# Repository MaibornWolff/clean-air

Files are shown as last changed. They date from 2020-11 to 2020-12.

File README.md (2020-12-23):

# Clean Air Device - an open UV-C aircleaner unit

## What is this?

This repository contains the building plans to build a DIY-air-cleaner based on UV-C radiation - the "cleanair" device.
The large device consists of 6 36W UV-C lamps in a flight case with extra space for electronics and the ESP32 control unit. The small one is able to handle up to 4 55W UV-C lamps and can be printed using a 3D printer capable of printing at least 22cm x 22cm blocks.

### Anycase Version

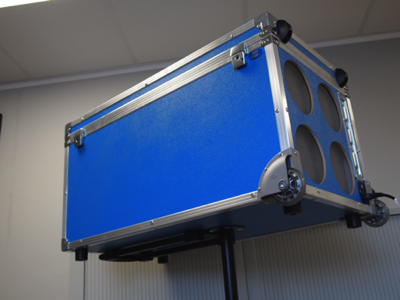
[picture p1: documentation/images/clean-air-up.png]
Clean Air Device
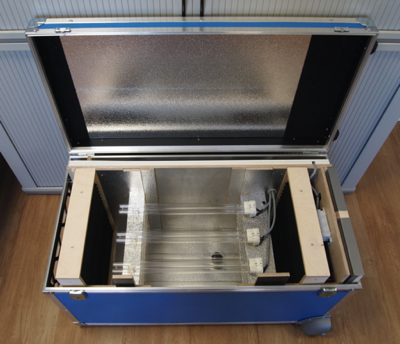
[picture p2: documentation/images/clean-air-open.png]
Clean Air Device
 

### 3D printable Version

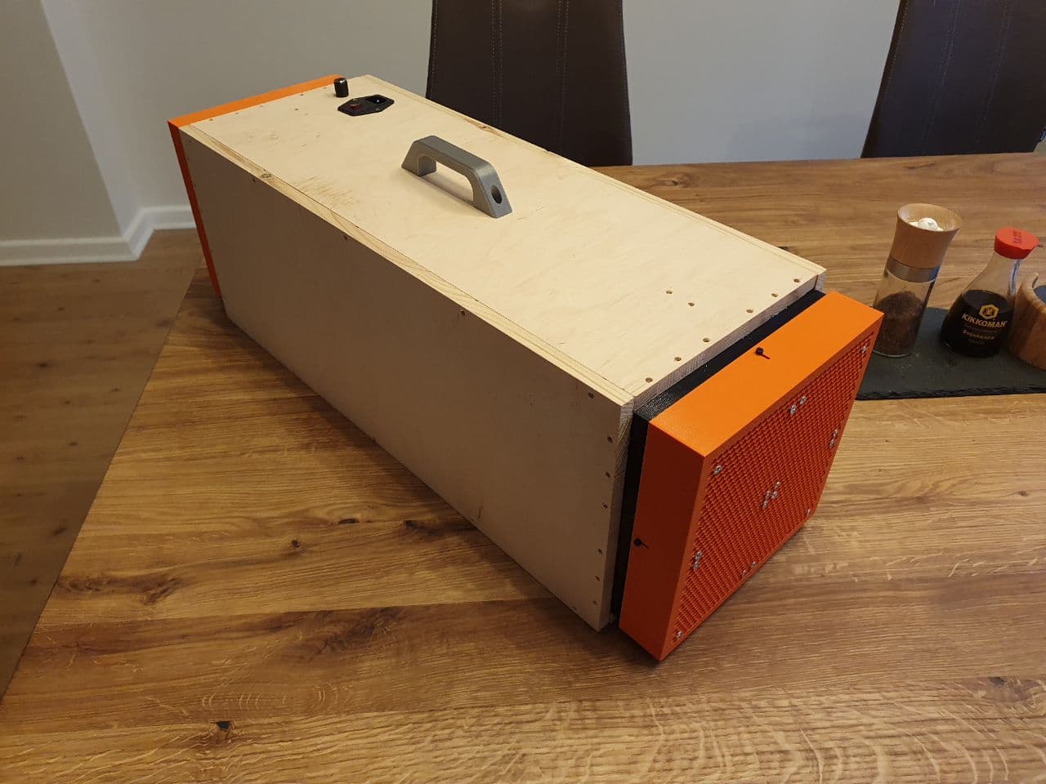
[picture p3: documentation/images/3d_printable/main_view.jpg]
3D printable Clean Air Device

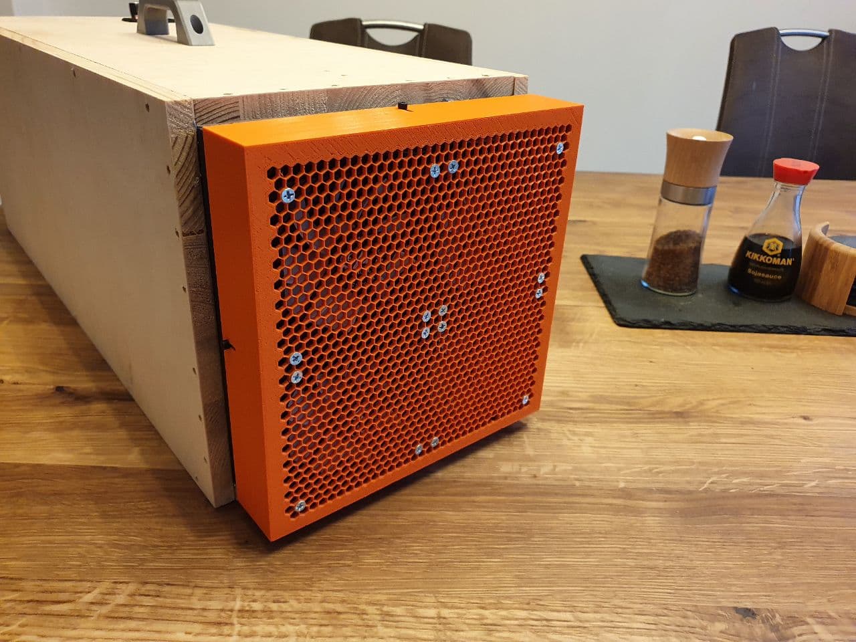
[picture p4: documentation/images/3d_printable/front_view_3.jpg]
3D printable Clean Air Device

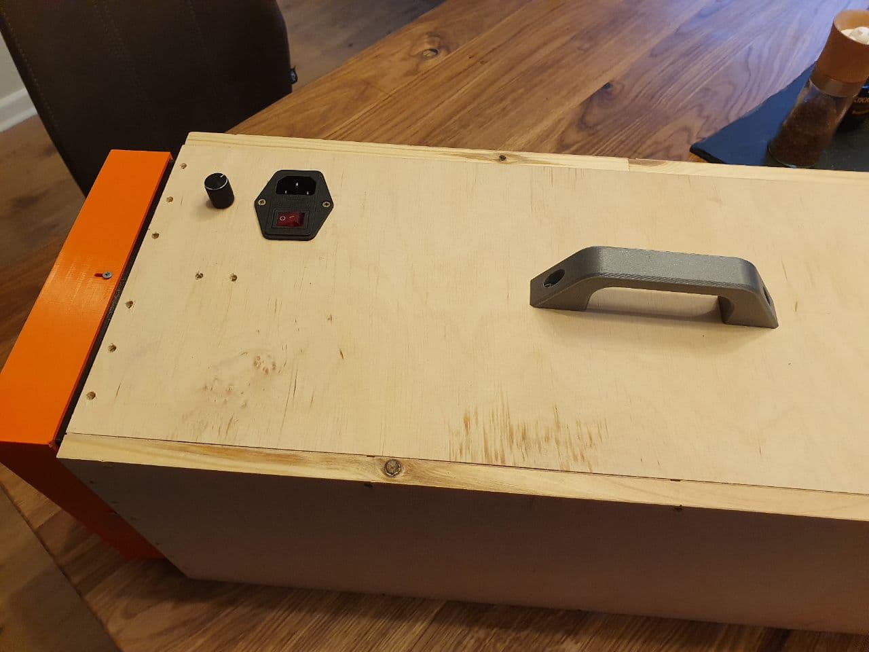
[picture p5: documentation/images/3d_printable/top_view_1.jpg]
3D printable Clean Air Device


## Why would I need this (what is the purpose)?

It seems reliable, that ultraviolet light (especially the UV-C variant) can help kill viruses.
On the other hand, UVC is dangerous to eyes and skin.

At MaibornWolff we put our engineering minds to it and created a solution which works for us.

**We build a mobile, safe container with UVC lights inside.**

Here are some reading information sources, if you want to read up on various opinions:

- https://www.medrxiv.org/content/10.1101/2020.05.31.20118588v3
- https://www.bbc.com/future/article/20200327-can-you-kill-coronavirus-with-uv-light
- https://www.cuimc.columbia.edu/news/far-uvc-light-safely-kills-airborne-coronaviruses
- https://pubmed.ncbi.nlm.nih.gov/32547908/

We estimated the irradiance inside the device as described in the [calculation (PDF)](documentation/theory.pdf).

## Getting started

In order to get started you have to decide if you want to build the large device or the small one. The large is device is mostly build by hand where the smaller one can be 3D-printed.

More information can be found in the [documentation section](documentation/README.md).

## Warning!

This device uses UV-C lamps which will damage skin and eyes. BE CAREFUL AND DO NOT TURN THE LAMPS ON OUTSIDE THE CASING!
Furthermore be aware of working with High Voltage for the lamps. CAUTION HIGH VOLTAGE!

## FAQ

### Why is it free?

We at MaibornWolff believe we have a responsibility to society, especially in these difficult times. As an IT company we had a good business year, regardless of Corona, and now it is time to use our knowledge in creating IT solutions to build an affordable and free air cleaner everyone can use.
We will not build our own "MaibornWolff Air Cleaner" unit and sell it. We have no whatsoever financial interest. Instead, we encourage you to help us make the device better, more easy to use, more cheap to produce, so everyone - companies, schools, kindergardens - could probably have one.

### What license are you using?

The code and documentation is licensed under the [MIT](LICENSE) license. The hardware documentation, build plans and 3d files are licensed under the [Creative Commons Attribution 3.0 Unported](cc-by-sa-3.0-unported.txt) license.

### How can I help?

Have a look at the [CONTRIBUTING](CONTRIBUTING.md) documentation. You can also join our [Slack Channel](https://maibornwolffcleanair.slack.com/) to get in touch with us.

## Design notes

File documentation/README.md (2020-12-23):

# Documentation

The documentation covers all information around the UV-C clean air units.

## DIY Hardware

### Calculations

Estimations about the irradiance and considerations about the room size for which such a device could be feasible are located [here](theory.pdf).

### 3D printable device

The small 3D printable model is a UV-C cleaner with up to 4 lamps and up to 8 fans. Based on our calculations the small device is capable of handling rooms with a size of up to 25,3m² (assuming 2.5m ceiling height), using 4x 55W UV-C lamps and fans with a total throughput of 380m³/h.

See [3D model documentation](3dmodel.md).

### Wooden device

The wooden device is a full sized DIY case, specced with 6 UV-C lamps and 4 fans.

See [wooden model documentation](allWoodModel.md).

### Electronics

- GPIO Pin 33 is to control the main fans via PWM signal.
- GPIO Pin 26 is to control the auxiliary fan via PWM signal.
- GPIO Pin 23 is to read the temperature coming from the temp sensor.
- GPIO Pin 21 connects to the "clock" of the rotary encoder (if in wrong dir, needs to get swapped with wire from Pin 17)
- GPIO Pin 17 connects to the "DT" of the rotary encoder (if in wrong dir, needs to get swapped with wire from Pin 21)
- GPIO Pin 16 connects to the "SW" of the rotary encoder.

Wire up the low voltage part like that:

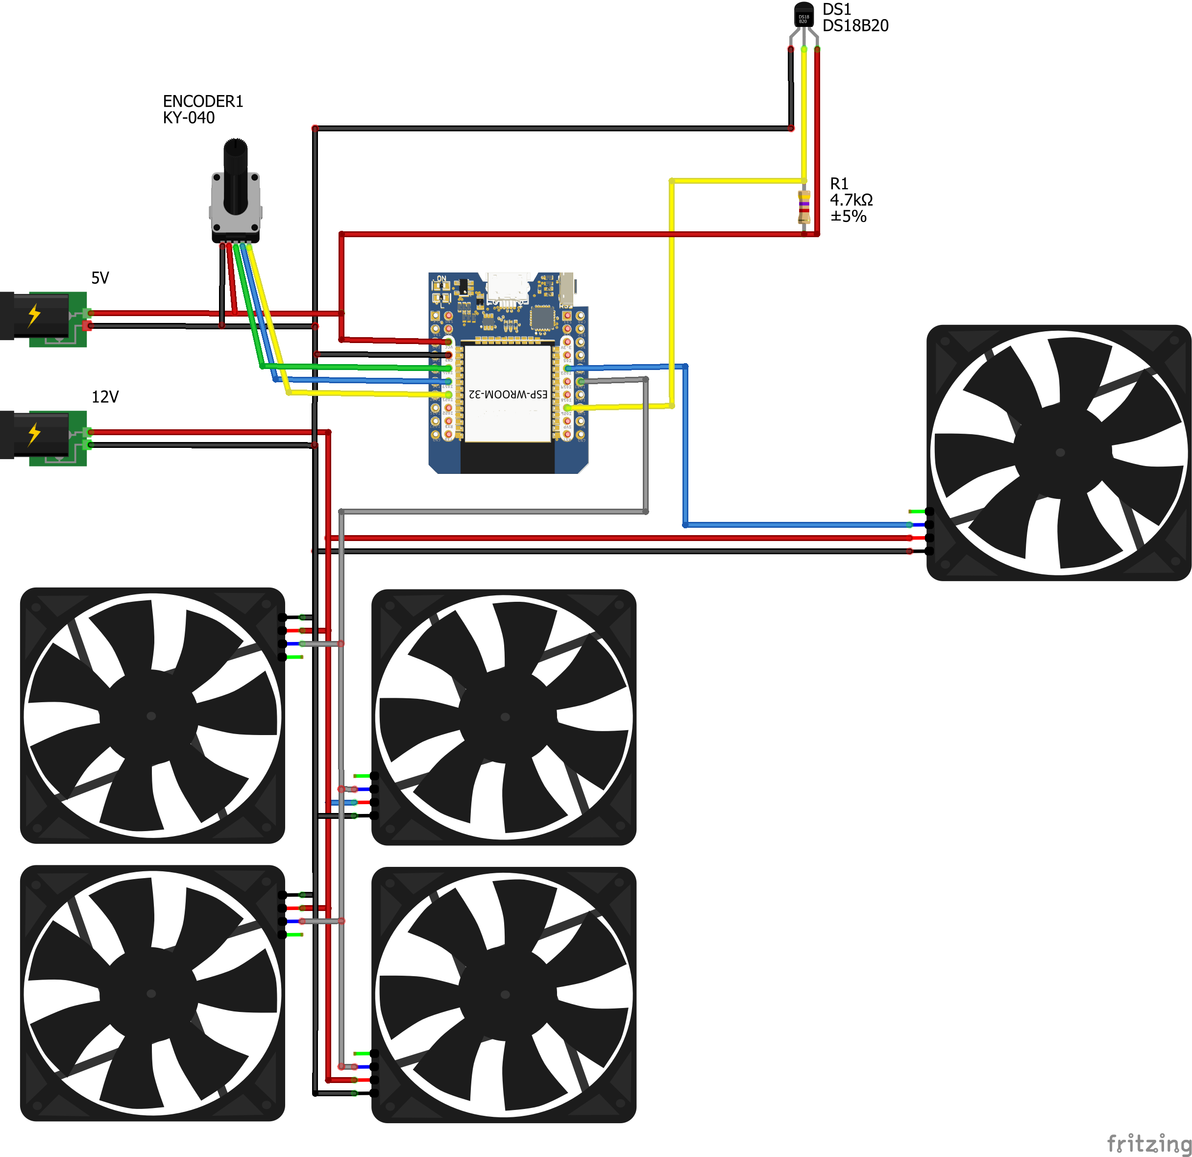
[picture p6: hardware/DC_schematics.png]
Low voltage schematics


The high voltage part is more dependent on the inverter as well as the plugs you use. On top of that it is more dangerous to work with 230V. If you do not know what you are doing you might rather want to look for professional help! Due to that a schematic for the high voltage part will not be provided. The individual recommended parts can be found within the specific devices documentation.

## Software

Use a tool like e.g. [ESPHome-Flasher](https://github.com/esphome/esphome-flasher) to flash the latest release onto your Wemos. If you'd like to build the software yourself, go to the Building section.

### Building

See [building documentation](software.md).

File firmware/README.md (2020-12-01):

## Instructions for Linux

- Install platformio.

- Install (udev rules)[https://docs.platformio.org/en/latest/faq.html#platformio-udev-rules].

- Add yourself to the dialout and tty group:

```sh
sudo usermod -a -G tty $USER
sudo usermod -a -G dialout $USER
sudo usermod -a -G plugdev $USER
```

Disconnect your board, then log out and log in again for the changes to take place. 

Check if your ESP32 is connected:

```sh
ll /dev | grep ttyUSB*
```

You should then be able to flash the code onto your board by running

```sh
platformio run --target upload --target monitor
```

Afterwards, an access point should spawn (namend ```CleanAirDevice```). The password is ```12345678```. Afterwards, the configuration page should be reachable under e.g. ```http://172.217.28.1/_ac``` (you need to fill in the correct IP address, of course).

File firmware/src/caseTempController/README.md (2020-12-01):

# Case Temperature Controller

Sub-program for regulating a PWM controlled fan to keep a steady temperature within the case.

Written for ESP32, Xinda Temperature Sensor, Noctua NF-A4x20 in C.

This program is basically implementing a PID controller. To understand the underlying calculation, check the following wikipedia article: https://en.wikipedia.org/wiki/PID_controller#Alternative_nomenclature_and_forms

# Circuit Diagram

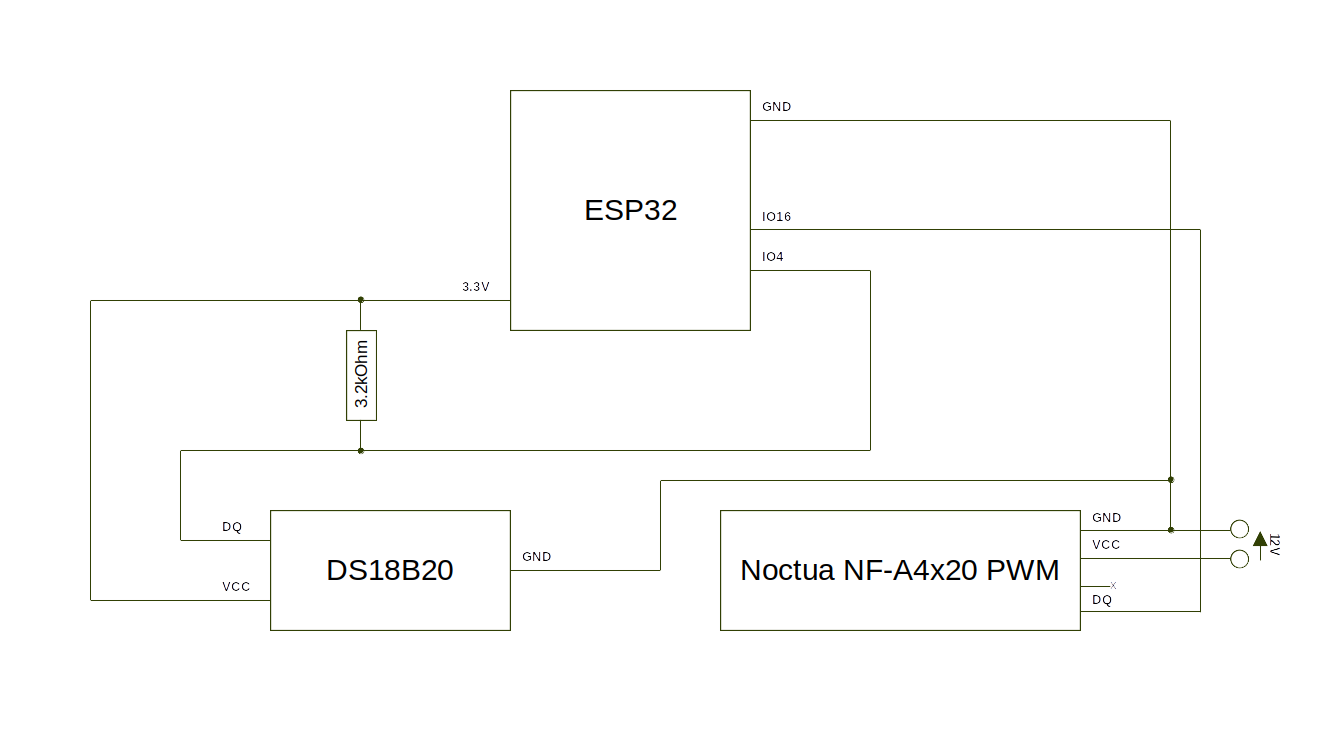
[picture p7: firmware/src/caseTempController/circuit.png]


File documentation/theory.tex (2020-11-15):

% !TEX encoding = UTF-8 Unicode
\documentclass[12pt]{scrartcl}
\usepackage{amsmath}
\usepackage{graphicx}
\usepackage{hyperref}
\usepackage{url}
\usepackage[utf8]{inputenc}
\usepackage{units}

\author{Michael Kiefer}\publishers{MaibornWolff GmbH, Versmannstr. 2, 20457 Hamburg}
\title{Calculations for the Clean-Air UVC device}

\begin{document}
\maketitle{}

\section{Concept}
We consider a set-up with air flowing through a cylinder, assuming the flow is independent of the position in the cylinder. At the center of the cylinder, we have the UVC lamp (a fluorescent tube). 
We want to calculate the energy that gets deposited on a virus particle while passing through the cylinder. The worst case is a virus passing at the wall of the cylinder, with the greatest distance to the lamp.

At that position, we have an Irradiance $I$ as
\begin{equation}
I   = \frac{E}{A_{\text{surface}}},  \label{eqn:irradiance}
\end{equation}
with the Energy $E$ and the side surface of the cylinder $A_{\text{surface}}$,

The outer surface of the tube is determined by the length $l$ and the radius $r$ of the tube as

\begin{equation}
A_{\text{surface}} = 2\pi r l.  \label{eqn:surface}
\end{equation}

The energy is determined by the power $P$ emitted by the lamps within the time $t$ that it takes for a volume element to pass through the irradiated part of the tube

\begin{equation}
E = P  t  \label{eqn:energy}
\end{equation}

We derive the time from the air flow $\Phi$, the volume $V$ that passes through the tube in a given time.
\begin{align}
\Phi &= V / t\\
\Rightarrow t &=V / \Phi
\end{align}

The volume is given by the geometry of the cylinder, using length and base area $A_{\text{base}}$
\footnote{we do not use the cylinder's radius fo calculating the area here, as we want to keep it for the generalization in section \ref{sect:multitube}.}
\begin{equation}
V = l A_{\text{base}} \label{eqn:volume}
\end{equation}

With equations \eqref{eqn:energy}, \eqref{eqn:volume} and \eqref{eqn:surface} in \eqref{eqn:irradiance}, we obtain
\begin{equation}
I =\frac{P }{\Phi } \frac{A_{\text{base}}}{2 \pi r }\label{eqn:irradiance_final}
\end{equation}

\section{Multiple lamps}\label{sect:multitube}
We want to estimate the irradiance created by multiple lamps at a certain position in our setup. At such a position, we can calculate the irradiance $I_i $ caused by each of the lamps $i$ with \eqref{eqn:irradiance_final} using the distance to the lamp as $r_{i}$. The resulting irradiance is simply the sum of these\footnote{$P$ in this case is the sum of the powers of the individual lamps $P_i$.}.
\begin{equation}
I_{\text{total}}=  \sum_{i} I_i = \frac{P A_{\text{base}}}{\Phi 2 \pi}  \sum_{i} \frac{1}{ r_i }
\end{equation}

In order to disable the virus particles, we need to expose them to a certain level of irradiation. With this targeted value $I_{\text{target}}$ given, we can calculate the maximum flow $\Phi_{\text{max}}$ that our device can process as

\begin{equation}
\Phi_{\text{max}}=  \frac{P A_{\text{base}}}{I_{\text{target}} 2 \pi}  \sum_{i} \frac{1}{ r_i }
\end{equation}

\section{Application to the MaibornWolff clean air device}

\begin{figure}
   \centering
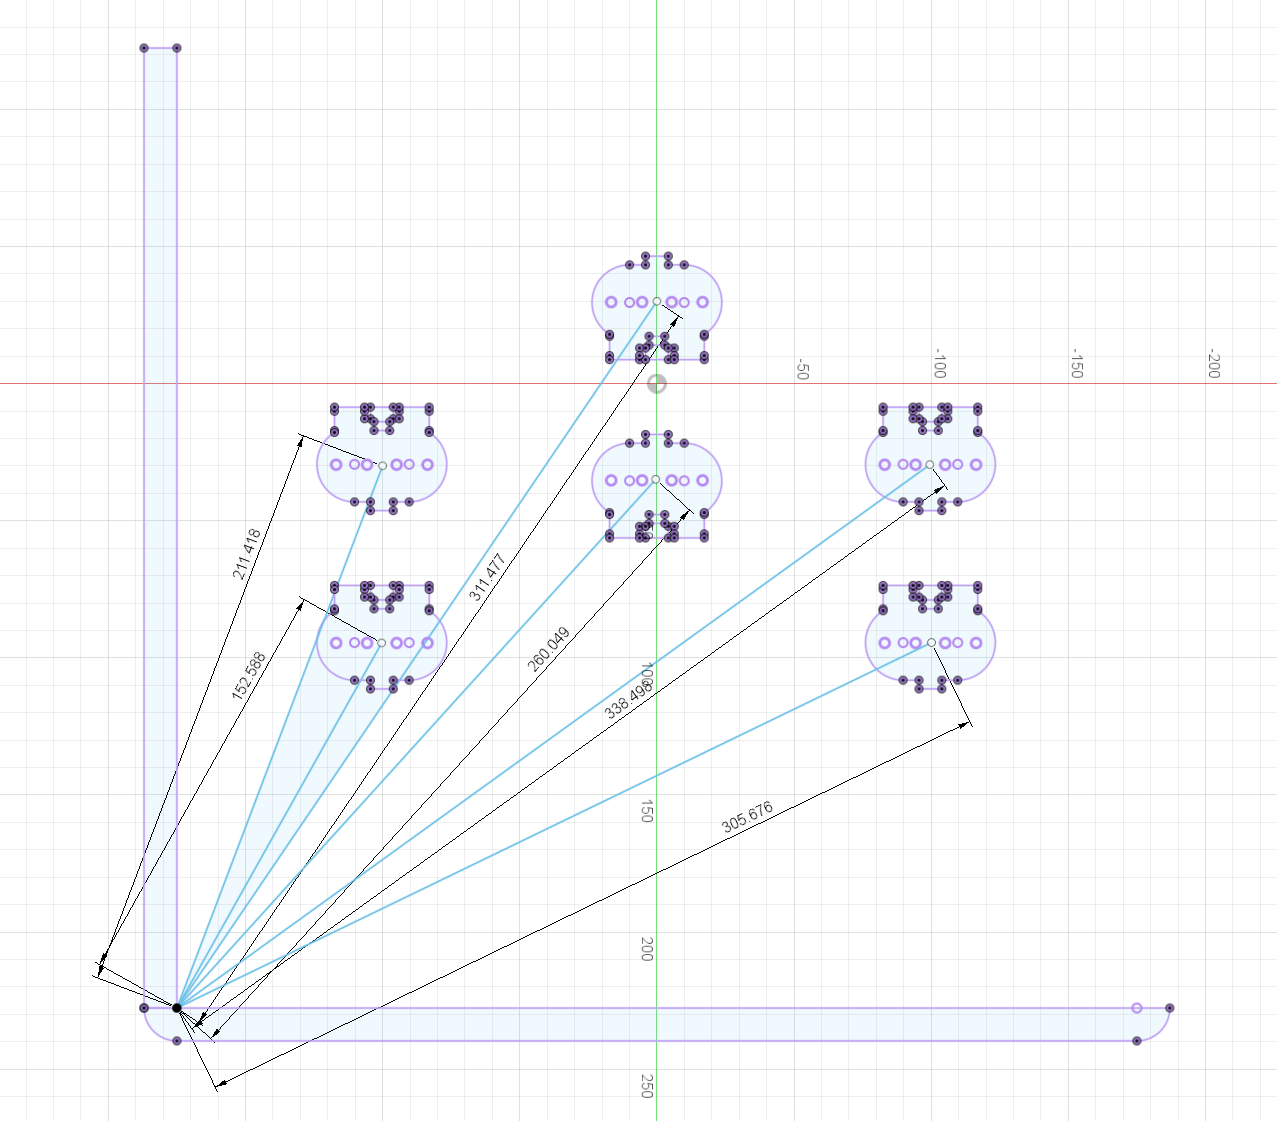
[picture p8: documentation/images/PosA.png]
    % requires the graphicx package
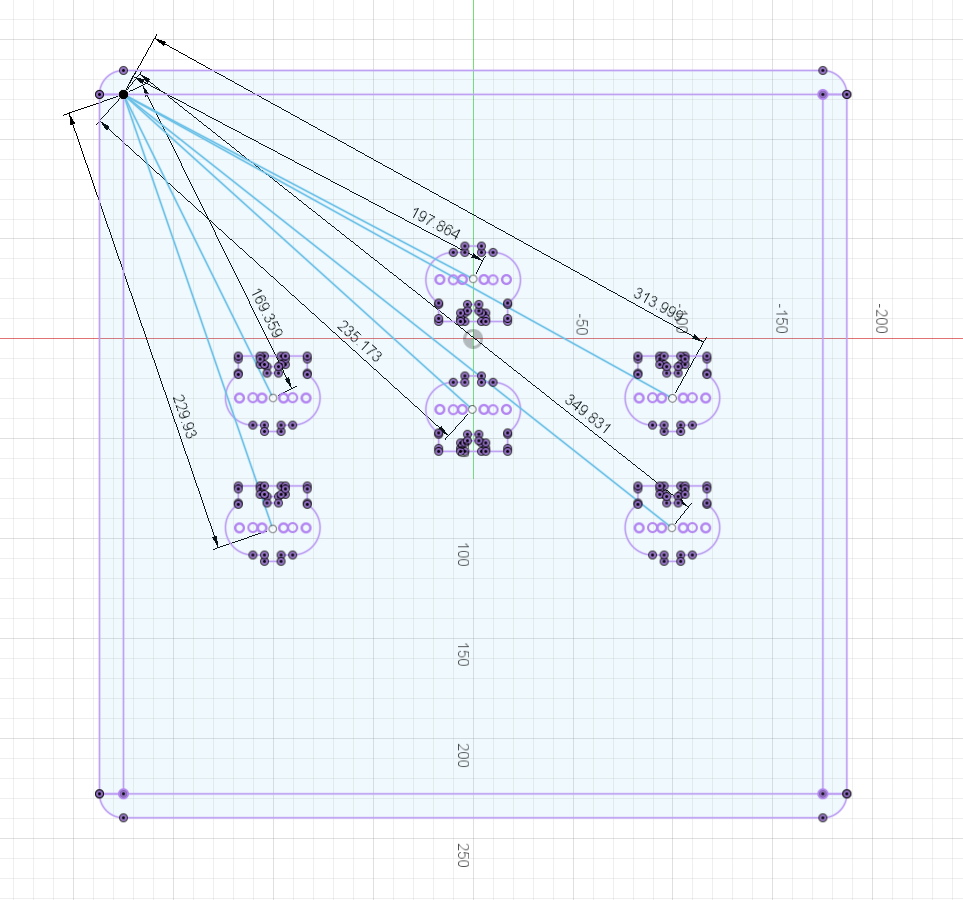
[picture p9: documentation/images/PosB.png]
    % requires the graphicx package
   \caption{Distances at position A (left) and B (right)}
   \label{fig:distances}
\end{figure}

Numbers on the irradiation dose vary. 
In order to deactivate coronavirus particles, \cite {ozog}  says that an irradiation of $\unit[10]{J/m^2}$ is sufficient. However, \cite{bianco} says that an irradiation of $\unit[37]{J/m^2}$ is needed. In \cite{hessling} this value is given as the probable value for the log-reduction dose which would mean that such an irradiation would at least deactivate 90\% of the virus particles. For the ongoing calculation, we aim at an irradiation with $\unit[120]{J/m^2}$ which would mean a log-3 reduction in case of the number given by \cite{hessling}.

In our set-up, the lamps each consume $\unit[36]{W}$ in electrical power and emit $\unit[12]{W}$ of UVC light.

The two sets of distances given in figure \ref{fig:distances} describe the positions that are furthest away from the lamps and thus the places where the irradiation is the weakest.

Using the excel sheet attached in the source repository, we calculate that the maximum throughput the device can tend to is in the range of $\unit[1000]{m^3/h}$. The WHO recommends an exchange rate of 6 air changes per hour \cite{who}. Assuming a height of $\unit[2.5]{m}$, this means that one device is appropriate for a room of up to $\unit[66]{m^2}$.

\begin{thebibliography}{9}

\bibitem{hessling}
   Heßling, Martin et al. 
   “Ultraviolet irradiation doses for coronavirus inactivation - review and analysis of coronavirus photoinactivation studies.”
   GMS hygiene and infection control vol. 15 Doc08. 
   14 May. 2020, 
   doi: https://doi.org/10.3205/dgkh000343
   
\bibitem{bianco}
  Andrea Bianco et al.,
  "UV-C irradiation is highly effective in inactivating and inhibiting SARS-CoV-2 replication"
  medRxiv 2020.06.05.20123463
  doi: https://doi.org/10.1101/2020.06.05.20123463 
  
\bibitem{ozog}
  David M. Ozog, et al.,
  The Effect of Ultraviolet C Radiation Against SARS-CoV-2 Inoculated N95 Respirators
  medRxiv 2020.05.31.20118588; doi: \url{https://doi.org/10.1101/2020.05.31.20118588}

\bibitem{who}
  Coronavirus disease (COVID-19): Ventilation and air conditioning in health facilities
  29 July 2020  Q\&A
  \url{https://www.who.int/news-room/q-a-detail/coronavirus-disease-covid-19-ventilation-and-air-conditioning-in-health-facilities}

\end{thebibliography}

\end{document}

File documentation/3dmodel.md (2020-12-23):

## Documentation

The printing time for the 3D Printable Model is about 85 hours (with 0.4mm nozzle, 0.2mm layer height)
cumulated, and you'll need about 1,5kg of PETG or ASA. You should not use PLA since it is not UV resistant. In
total, the 3D-printable device will cost you about 175€ excl. the print material, the electrical bill and your time.
The UV-C aircleaner can also be found on [thingiverse](https://www.thingiverse.com/thing:4649824)

### Used Hardware

For the .stl files please check the folders within this directory. The also contain a file "required_parts.txt" which
describes the amount required of each part. All other non-3D-printable parts are listed within this document.

#### List of common parts with links:

| # | Description | Note | Link | Price in €  |
| --- | --- | --- | --- | --- |
| 1/2 | Inverter 55W | can be adjusted according to wattage of lamps | [amazon.de](https://www.amazon.de/gp/product/B00I0QUFR4/) | 13,54 |
| 1 | 12V PSU | | [amazon.de](https://www.amazon.de/gp/product/B00A9UP8P8/) | 17,99 |
| 1/2 | UVC Mount | | [amazon.de](https://www.amazon.de/gp/product/B0018LGB4E/) | 4,96 |
| 2/4 | UVC Lamp 55W | can be adjusted to up to 95W | [amazon.de](https://www.amazon.de/gp/product/B002VLGJOW/) | 19,13 |
| 1 | 5V PSU | Optional, a 12v to 5v converter can also be used | [amazon.de](https://www.amazon.de/gp/product/B079138QY1/) | 8,46 |
| 1 | AC Plug with fuse | | [amazon.de](https://www.amazon.de/gp/product/B01FQVM9EM/) | 6,99 |
| 4/8 | 12V 92mm PWM Fan | either use only 4 in the front or 4 in the front and 4 in the back | [amazon.de](https://www.amazon.de/ARCTIC-F9-PWM-Standardgeh%C3%A4use-L%C3%BCfterdrehzahl/dp/B00H3SVWF4/) / [mindfactory.de](https://www.mindfactory.de/product_info.php/Titan-TFD-9225H12ZP-KE-RB--92x92x25mm-2700-U-min-10-25-dB-A--schwarz-we_1030365.html) | 3,60 / 9.02 |
| 1 | ESP32 Mini | | [amazon.de](https://www.amazon.de/AZDelivery-Bluetooth-Internet-Entwicklungsboard-kompatibel/dp/B08BTRQNB3/) | 8,99 |
| 1 | Rotary Knob KY-040 | | [amazon.de](https://www.amazon.de/WayinTop-Encoder-Drehgeber-Drehwinkelgeber-Druckknopf/dp/B07T3672VK/) | 9,99 |
| - | M3 Screws 15mm | use a lot | - | - |
| - | M3 Screws 30mm | use a few | - | - |
| - | Wood Screws 15mm | use a lot | - | - |
| 1 | Aluminum self adhesive tape | A roll is enough to build one hybrid wooden device | [amazon.de](https://www.amazon.de/gp/product/B08C5JPV12) | 10,00 |
| - | Cables | use a lot and in different variations, ref to the specs of the inverter | - | - |

#### 3D Printable Aluminum Hybrid Model:

| # | Description | Link | Price in € |
| --- | --- | --- | --- |
| 4 | Aluminum L Profile | [ebay.de](https://www.ebay.de/itm/Aluminium-Winkel-Alu-L-Profil-Alu-Schiene-Aluprofil-Winkelprofil-Aluwinkel/282319979439)  | 2,42 |
| 4 | Aluminum Plate 600x200mm | [ebay.de](https://www.ebay.de/itm/0-5-4mm-Aluminium-Blech-Platte-Alublech-Aluplatte-Feinblech-mit-Schutzfolie/264476529936) | 18,45 |

#### 3D Printable Wood Hybrid Model:

| # | Description | Link | Price in € |
| --- | --- | ---- | --- |
| 2 | Wooden Plate 600x230mmx10mm | - | 5,00 |
| 2 | Wooden Plate 600x210mmx10mm | - | 5,00 |

#### Parts used from to other sources which need to be printed:

| # | Description | Link |
| --- | --- | --- |
| 1 | Knob | [thingiverse.com](https://www.thingiverse.com/thing:1465938) |
| 1 | Handle | [thingiverse.com](https://www.thingiverse.com/thing:4619895) |

#### What you'll need in addition to that

- An (electric) screwdriver
- Wood/Metal drills (and electric screwdriver/o.e.)

### How to build it

### Electronic Setup

Wire up the low voltage part like that:

Low voltage schematics

### ESP Control Unit

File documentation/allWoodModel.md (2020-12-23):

# DIY Version with items from your local hardware store

<p align="center">
  
</p>
This hardware version is mainly build out of wood, which can be cut to length by most hardware stores or in a home workshop. For the light shutters, a combination of angle-profiles and wooden mounts is used.
Those mounts can either be cut with a CNC, 3d printed or carved with hand tools. A technical drawing is included in this repository. Due to the different methods to produce this parts, those shutters need to either be glued, screwed or held otherwise in to place after installing them like shown in the animation above.

## Required Materials

### Wooden parts:

| # required | length | width | thickness | Note |
| --- | --- | ----- | --- | --- |
| 2 | 818mm  | 450mm | 9mm | sides |
| 2 | 450mm  | 350mm | 9mm | front and back |
| 3 | 800mm  | 350mm | 9mm | top, bottom and divider  |
| 8 | 350mm  | 10mm  | 10mm | wooden strip 10mm\*10mm  |
| 4 | 350mm  | 40mm  | 9mm | mounting for light tubes |
| 4 | 350mm  | 50mm  | 9mm | light filter mount |

### Electronics:

| # required | Description | Model suggestion | Link |
| --- | --- | --- | --- |
| 4 | 140mm PWM fan | Noctua NF-A14 | [amazon.de](https://www.amazon.de/-/en/Noctua-NF-A14-PWM-case-fan/dp/B00CP6QLY6) |
| 1 | 12V DC Supply | | [amazon.de](https://www.amazon.de/-/en/Innovate-Transformer-12-24-Driver-Supply/dp/B01AALEXS8) |
| 6 | UV-C 36W disinfection lamp | Philips TUV PL-L 36W | [amazon.de](https://www.amazon.de/-/en/Philips-PLL36-865-2G11-6500K/dp/B0019CG6D8) |
| 3 | Electric ballast | Philips EVG HF-S 2x 36 W  | [amazon.de](https://www.amazon.de/-/en/Philips-Electronic-Ballast-Fluorescent-Compact/dp/B00OTXR71E/) |
| 6 | lamp holder | 2g11 | [amazon.de](https://www.amazon.de/-/en/Vossloh-Assembly-Frame-Mount-2G11-PL/dp/B0018LGB4E) |
| 6 | lamp clips | | [amazon.de](https://www.amazon.de/-/en/Houben-101393-mechanical-accessory-4014364013947/dp/B000ONOQF8) |
| 1 | 50mm PWM fan | | [amazon.de](https://www.amazon.de/-/en/Noctua-NF-A4x10-PWM-Premium-Quiet/dp/B07DXRNYNX) |
| 1 | temperature sensor | ds18b20 | [amazon.de](https://www.amazon.de/-/en/AZDelivery-DS18b20-1m-DS18B20-Parent/dp/B01MZG48OE/) |
| 1 | ESP32 | Wemos D1 ESP32 | [amazon.de](https://www.amazon.de/-/en/AZDelivery-Bluetooth-Internet-Development-Compatible/dp/B08BTLYSTM/) |
| 1 | rotary encoder | | [amazon.de](https://www.amazon.de/-/en/WayinTop-KY-040-Encoder-Rotating-Arduino/dp/B07T3672VK/) |
| 1 | 12V/5V DC/DC | | [amazon.de](https://www.amazon.de/-/en/AZDelivery-XL4015-Voltage-Converter-1-25-32/dp/B07SRXR1VT) |
| 1 | 4.7k Ohm Resistor | | [amazon.de](https://www.amazon.de/-/en/Metal-film-resistor-pack-10/dp/B01LXS3YX2/) |
| use a lot  | M3 Woodscrews 25mm | e.g. Spax | - |
| use a lot  | Wires, 1mm² should fit the inverter | | - |
| 1 | Aluminum self adhesive tape | A roll shouldbe be enough | [amazon.de](https://www.amazon.de/gp/product/B08C5JPV12) |

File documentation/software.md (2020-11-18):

# Software
The firmware of the ESP32 control unit is used to control the fan speed knob and to provide over-the-air features like automatic updates.

This documentation shows how to build the firmware on your local machine.

## Prerequisites

### PlatformIO
Platform IO is used to build the ESP firmware. PlatformIO is a cross-platform, cross-architecture, multiple framework, professional tool for embedded software development.
The documentation of platform io can be found here: https://docs.platformio.org/en/latest/

In order to build the software you need the PlatformIO CLI installed on your system. The main documentation can be found here: https://docs.platformio.org/en/latest/core/installation.html#piocore-install-shell-commands

Short documentation for Linux and MacOS:

Platformio is a python cli tool. You need python3 to run it and it can be installed using pip:

```
pip install platformio
```

For more complex installation variante (virtual python env or Windows) please refer to the  main documentation (see link above)

### Drivers - MacOS specific
#### ESP32
For the ESP32 uses the CH340 usb2serial chipset no further drivers are needed.

#### ESP8266
In order to acceess a D1 Mini/NodeMCU a USB to serial driver needs to be installed to use the CP210x USB to UART Bridge VCP. It can be found here:
https://www.silabs.com/Support%20Documents/Software/Mac_OSX_VCP_Driver.zip

Further documentation:
* https://cityos-air.readme.io/docs/1-mac-os-usb-drivers-for-nodemcu#13-nodemcu-v10-driver

#### Troubleshooting

After the installation of the drivers, it should be possible for you to connect the device via USB establish a serial connection. When entering

```
ls /dev/cu.*
```

you should see a device that is named something like:

```
/dev/cu.usbserial-0203810B
```

If this is not the case, try the following:

- [Check](https://www.dignited.com/50330/usb-data-cable-vs-usb-charging-cable/) if your USB cable is actually able to transfer data and it's not just a charger cable.
- Follow the instructions listed [here](https://docs.espressif.com/projects/esp-idf/en/latest/esp32/get-started/macos-setup.html) to make sure your system is configured properly.
- If nothing helps, manually install the correct ESP32 driver for your system from [here](https://www.ftdichip.com/Drivers/VCP.htm).

## Building

To build the firmware change in the CleanAir directory and issue the platformio run subcommand:

```
cd CleanAir
platformio run
```

To upload the firmware to your ESP32 issue the following command:

```
platformio run --target upload
```

Please note that you need to have configured the correct serial port to do the initial upload. To get a list of all available ports on your system you can run

```
platformio device list
```

If your upload port is not select automatically you can add the port configuration to your upload command:

```
platformio run --target upload --upload-port <upload port>
```

## Usage

## Further documentation

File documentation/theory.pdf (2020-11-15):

# Calculations for the Clean-Air UVC device

## Michael Kiefer

## November 12, 2020 MaibornWolff GmbH, Versmannstr. 2, 20457 Hamburg

## 1 Concept

We consider a set-up with air flowing through a cylinder, assuming the flow is independent of the position in the cylinder. At the center of the cylinder, we have the UVC lamp (a fluorescent tube). We want to calculate the energy that gets deposited on a virus particle while passing through the cylinder. The worst case is a virus passing at the wall of the cylinder, with the greatest distance to the lamp.
At that position, we have an Irradiance I as

I =

E

Asurface

, | (1)

with the Energy E and the side surface of the cylinder Asurface,
The outer surface of the tube is determined by the length l and the radius r of the tube as
Asurface = 2πrl. | (2)

The energy is determined by the power P emitted by the lamps within the time t that it takes for a volume element to pass through the irradiated part of the tube

E = P t | (3)

We derive the time from the air flow Φ, the volume V that passes through the tube in a given time.

Φ = V/t | (4)
⇒ t = V/Φ | (5)

1

The volume is given by the geometry of the cylinder, using length and base area Abase

1
V = lAbase | (6)

With equations (3), (6) and (2) in (1), we obtain

I =

P
Φ

Abase
2πr

(7)

## 2 Multiple lamps

We want to estimate the irradiance created by multiple lamps at a certain position in our setup. At such a position, we can calculate the irradiance Ii caused by each of the
lamps i with (7) using the distance to the lamp as ri | . The resulting irradiance is simply
the sum of these²

Itotal =

X

i

Ii =

P Abase
Φ2π

X

i

1
ri

(8)

In order to disable the virus particles, we need to expose them to a certain level of irradiation. With this targeted value Itarget given, we can calculate the maximum flow Φmax that our device can process as

Φmax =

P Abase

Itarget2π

X

i

1
ri

(9)

## 3 Application to the MaibornWolff clean air device

Numbers on the irradiation dose vary. In order to deactivate coronavirus particles, [3] says that an irradiation of 10 J/m²
is sufficient. However, [2] says that an irradiation of 37 J/m²
is needed. In [1] this value is given as the probable value for the log-reduction dose which would mean that such an irradiation would at least deactivate 90% of the virus particles. For the ongoing calculation, we aim at an irradiation with 120 J/m² which would mean a log-3 reduction in case of the number given by [1].
In our set-up, the lamps each consume 36W in electrical power and emit 12W of UVC light.
The two sets of distances given in figure 1 describe the positions that are furthest away from the lamps and thus the places where the irradiation is the weakest.
Using the excel sheet attached in the source repository, we calculate that the maximum throughput the device can tend to is in the range of 1000 m³/h. The WHO recommends an exchange rate of 6 air changes per hour [4]. Assuming a height of 2.5 m, this means that one device is appropriate for a room of up to 66 m²

1we do not use the cylinder’s radius fo calculating the area here, as we want to keep it for the generalization in section 2.
2P in this case is the sum of the powers of the individual lamps Pi

2

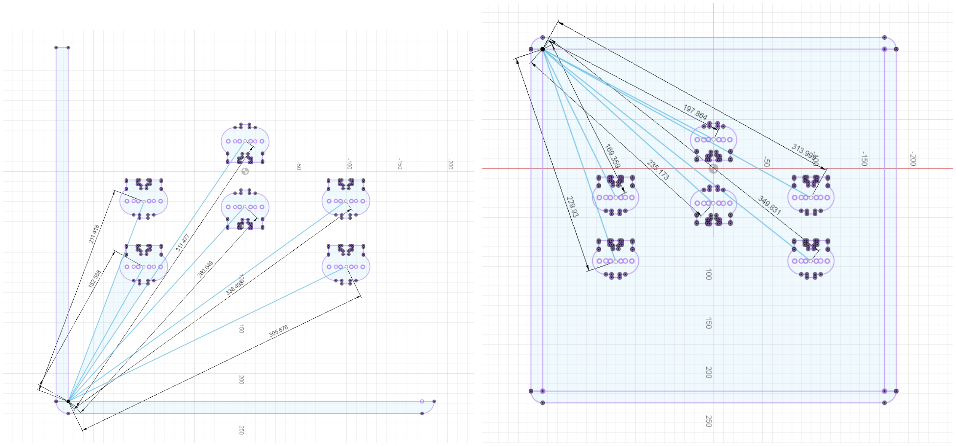
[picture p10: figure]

Figure 1: Distances at position A (left) and B (right)

## References

[1] Heßling, Martin et al. “Ultraviolet irradiation doses for coronavirus inactivation - review and analysis of coronavirus photoinactivation studies.” GMS hygiene and infection control vol. 15 Doc08. 14 May. 2020, doi: https://doi.org/10.3205/dgkh000343
[2] Andrea Bianco et al., ”UV-C irradiation is highly effective in inactivating and inhibiting SARS-CoV-2 replication” medRxiv 2020.06.05.20123463 doi: https://doi.org/10.1101/2020.06.05.20123463
[3] David M. Ozog, et al., The Effect of Ultraviolet C Radiation Against SARS-CoV-2 Inoculated N95 Respirators medRxiv 2020.05.31.20118588; doi: https://doi.org/10.1101/2020.05.31.20118588 (https://doi.org/10.1101/2020.05.31.20118588)
[4] Coronavirus disease (COVID-19): Ventilation and air conditioning in health
facilities 29 July 2020 Q&A https://www.who.int/news-room/q-a-detail/coronavirus-disease-covid-19-ventilation-and-air-conditioning-in-health-facilities (https://www.who.int/news-room/q-a-detail/coronavirus-disease-covid-19-ventilation-and-air-conditioning-in-health-facilities)

3

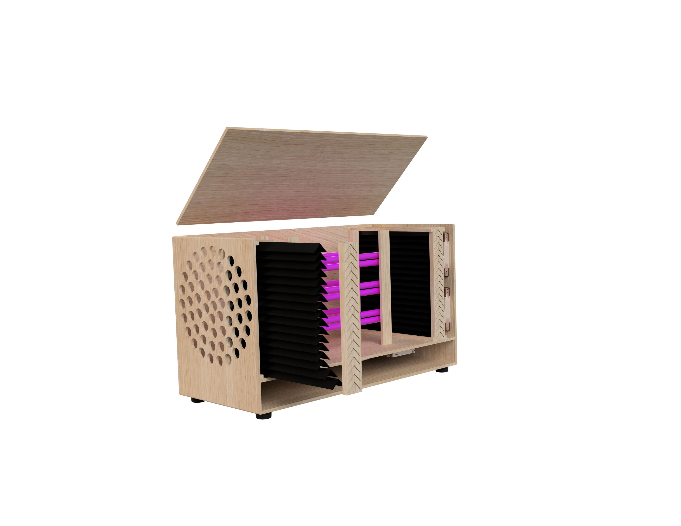
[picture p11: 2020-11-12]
hardware/all_wood/pictures/explosion2.png

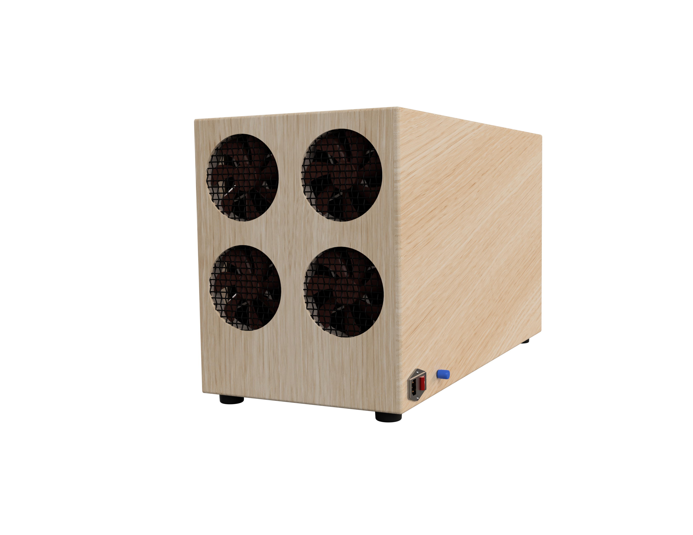
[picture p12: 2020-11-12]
hardware/all_wood/pictures/backview.png

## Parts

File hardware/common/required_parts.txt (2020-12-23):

2x honeycombfront (to your fan likes)
2x uv_back_holder
1x 230_protector
4x vorschaltgeräteschutz
1x wemos_case

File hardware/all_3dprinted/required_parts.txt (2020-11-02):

3D Prints:
- 2x lichtschutz
- 2x universalBoxPlate_uvc_holder
- 2x uvc_holder
- 16x universalBoxPlate_adapter
- 9x universalBoxPlate_clean
- 1x universalBoxPlate_io

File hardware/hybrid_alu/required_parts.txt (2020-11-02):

3D Prints:
- 2x lichtschutz
- 2x uvc_holder_alu
- 1x schablone_alu 

Other:
- 2x 60x20x0.3cm aluminum plates
- 4x Part #5

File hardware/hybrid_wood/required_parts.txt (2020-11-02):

3D Prints:
- 2x lichtschutz_wood
- 2x uvc_holder_wood
- 1x schablone_wood_narrow
- 1x schablone_wood_wide

Other:
- 2x 60x21x0.5cm wooden plates
- 2x 60x22x0.5cm wooden plates
- 4x Part #5

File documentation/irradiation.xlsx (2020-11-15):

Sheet: Position A
 |  | Position |  | UVC power |  | Box
Dimension | Lamp | distance from lamp |  | per lamp | total | length | width/height | base area | targeted irradiation | maximal flow
Symbol in PDF | i | ri | 1/ri | Pi | P | l |  | Abase | Itarget | Φmax
unit |  | mm | 1/m | W | W | mm | mm | m2 | J/m2 | m3/h
 | A | 211 | 4.739336493 | 12 | 72 | 400 | 350 | 0.1225 | 120 | 1036.686804 | 69.11245361
 | B | 152 | 6.578947368
 | C | 311 | 3.215434084
 | D | 260 | 3.846153846
 | E | 338 | 2.958579882
 | F | 305 | 3.278688525
 | Sum |  | 24.6171402

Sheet: Position B
 |  | Position |  | UVC power |  | Box
Dimension | Lamp | distance from lamp |  | per lamp | total | length | width/height | base area | targeted irradiation | maximal flow
Symbol in PDF | i | ri | 1/ri | Pi | P | l |  | Abase | Itarget | Φmax
unit |  | mm | 1/m | W | W | mm | mm | m2 | J/m2 | m3/h
 | A | 169 | 5.917159763 | 12 | 72 | 400 | 350 | 0.1225 | 120 | 1074.471415
 | B | 230 | 4.347826087
 | C | 198 | 5.050505051
 | D | 235 | 4.255319149
 | E | 324 | 3.086419753
 | F | 350 | 2.857142857
 | Sum |  | 25.51437266

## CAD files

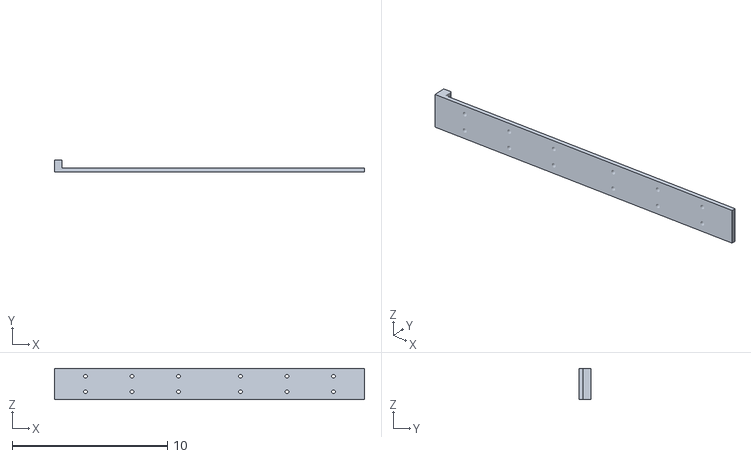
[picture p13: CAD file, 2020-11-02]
hardware/all_3dprinted/universalboxplate_adapter.stl
20.0 x 0.75 x 2.00

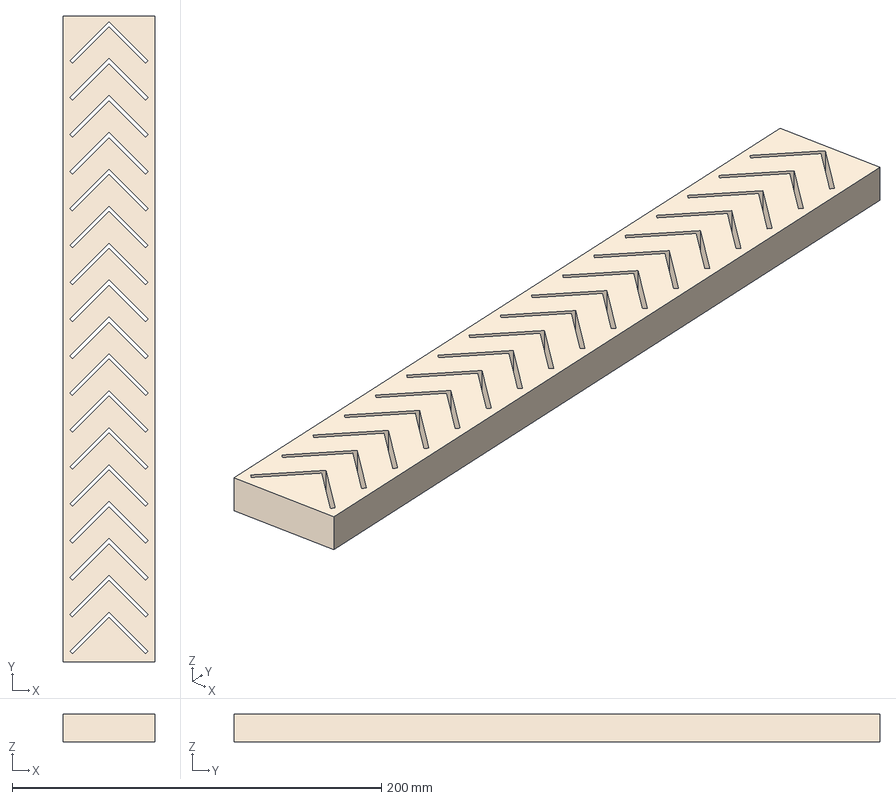
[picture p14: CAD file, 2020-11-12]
hardware/all_wood/light shutters/shutter_mount.step
50.0 x 350.0 x 15.0 mm

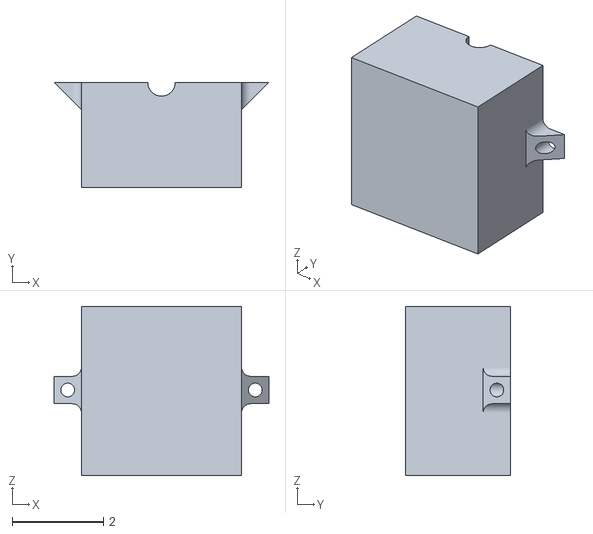
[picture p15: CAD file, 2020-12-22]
hardware/common/vorschaltgeräteschutz.stl
4.70 x 2.30 x 3.70

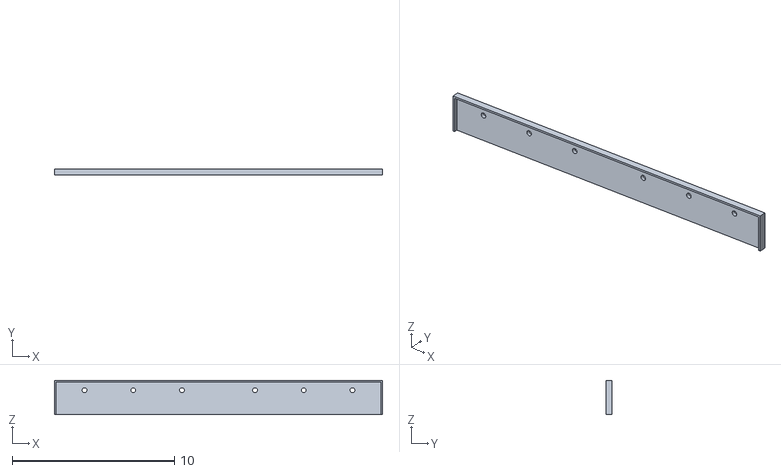
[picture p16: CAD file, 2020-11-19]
hardware/hybrid_alu/schablone_alu.stl
20.2 x 0.4 x 2.10

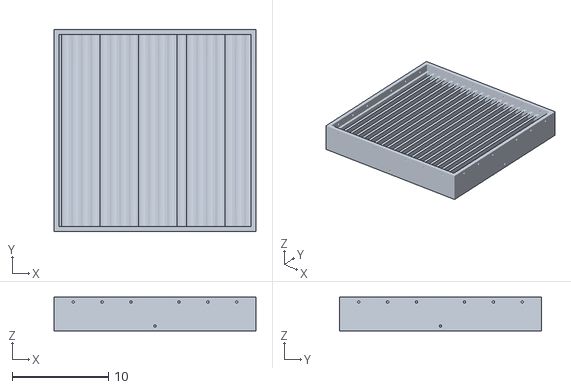
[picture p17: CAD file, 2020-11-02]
hardware/hybrid_wood/lichtschutz_wood.stl
21.0 x 21.0 x 3.50

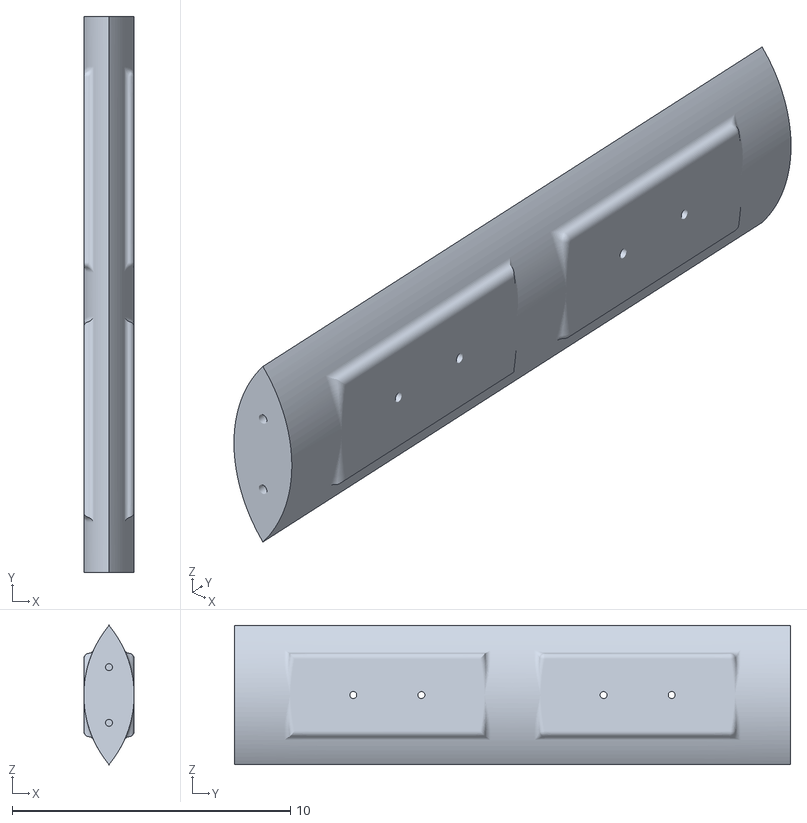
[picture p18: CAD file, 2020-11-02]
hardware/all_3dprinted/uvcholder.stl
1.81 x 20.0 x 5.00

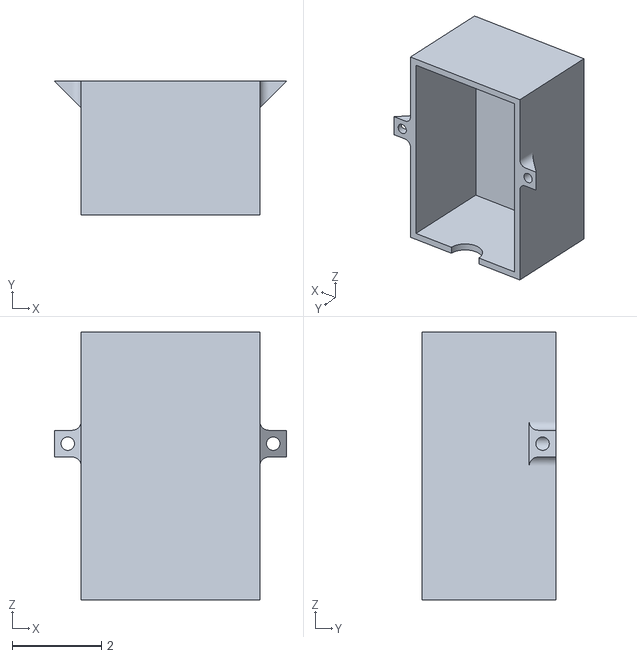
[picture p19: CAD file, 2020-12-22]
hardware/common/wemos_case.stl
5.20 x 3.00 x 6.00

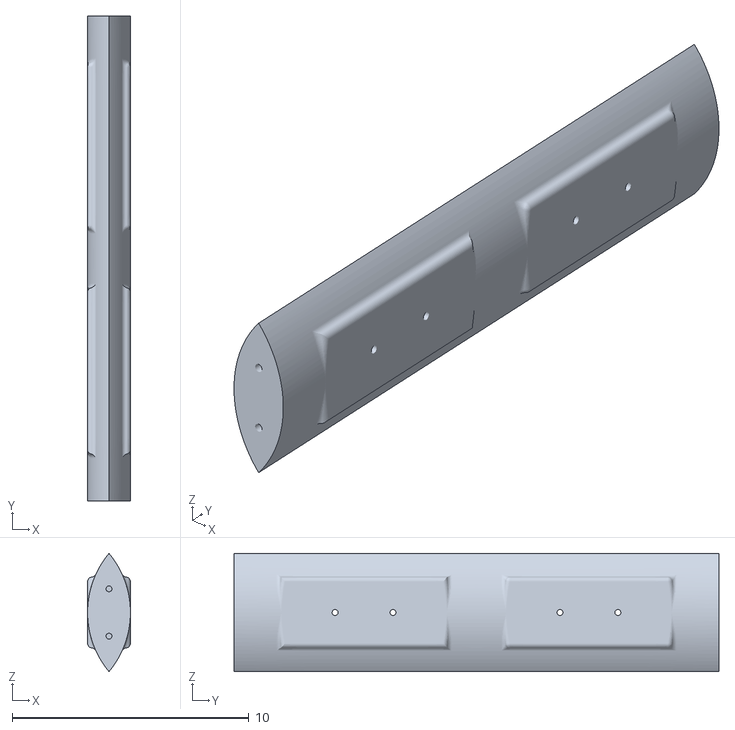
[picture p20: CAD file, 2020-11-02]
hardware/hybrid_alu/uvcholder_alu.stl
1.81 x 20.5 x 5.00

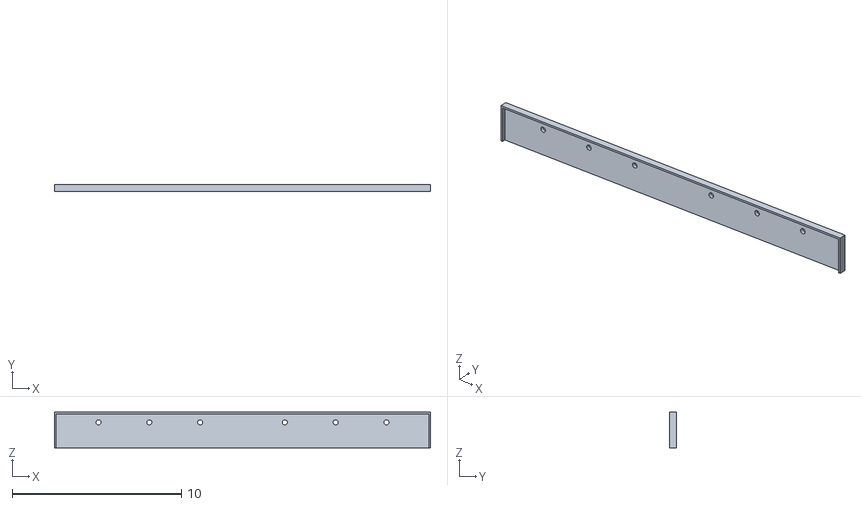
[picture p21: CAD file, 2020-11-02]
hardware/hybrid_wood/schablone_wood_wide.stl
22.2 x 0.4 x 2.10

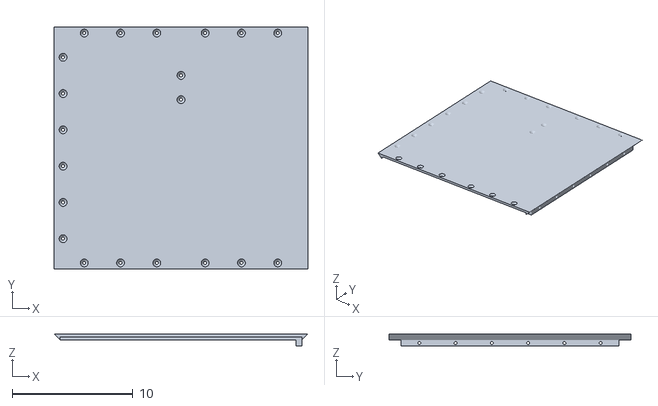
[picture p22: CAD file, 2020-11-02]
hardware/all_3dprinted/universalBoxPlate_uvc_holder.stl
21.0 x 20.0 x 1.00

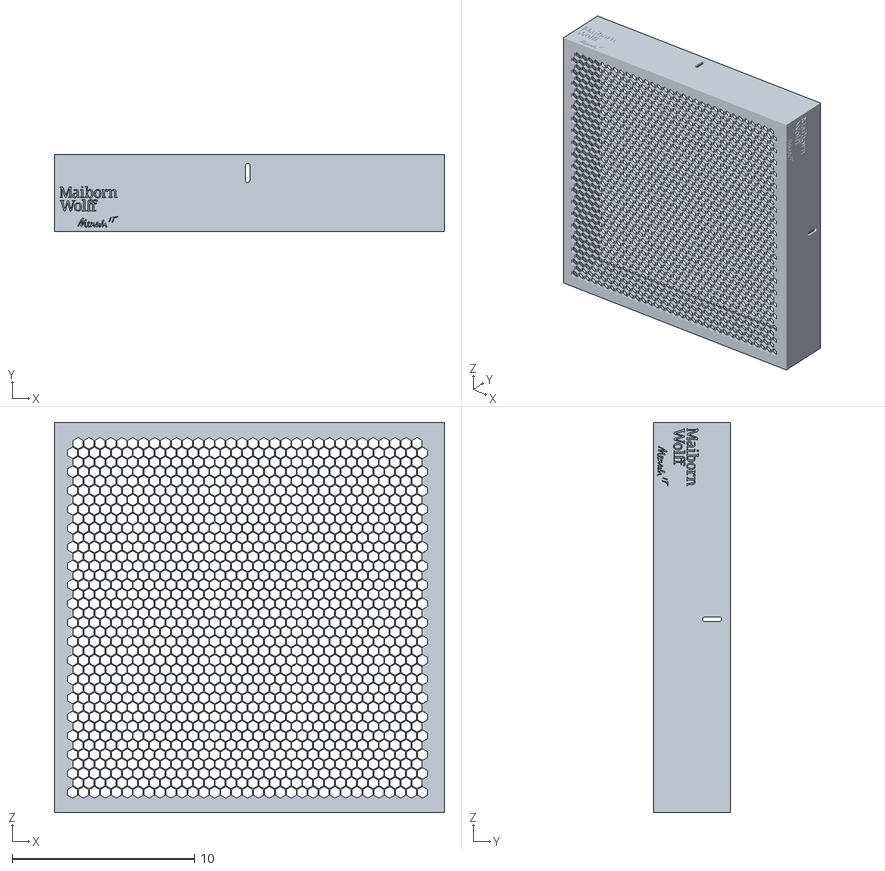
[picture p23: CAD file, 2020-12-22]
hardware/common/honeycombfront_normal_fan.stl
21.4 x 4.20 x 21.4

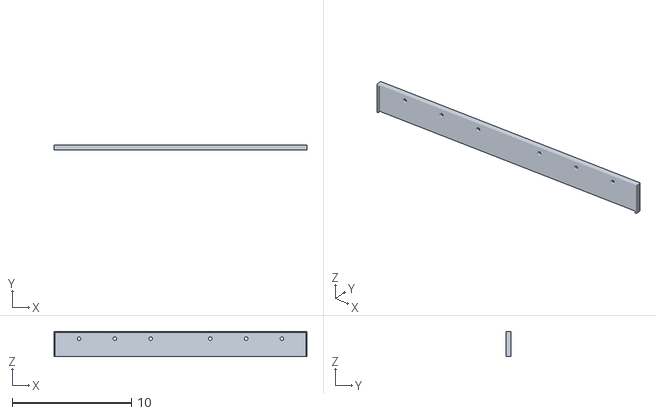
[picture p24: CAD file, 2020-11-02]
hardware/hybrid_wood/schablone_wood_narrow.stl
21.2 x 0.4 x 2.10

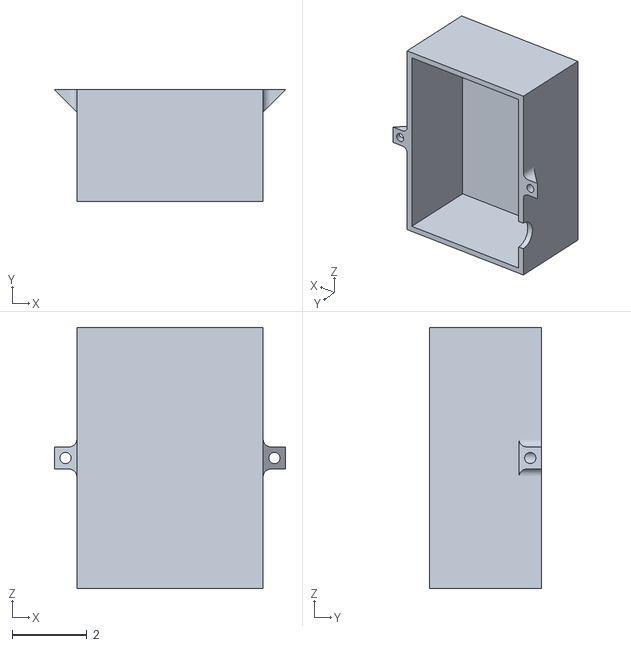
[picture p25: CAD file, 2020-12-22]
hardware/common/230v_protector.stl
6.20 x 3.00 x 7.00

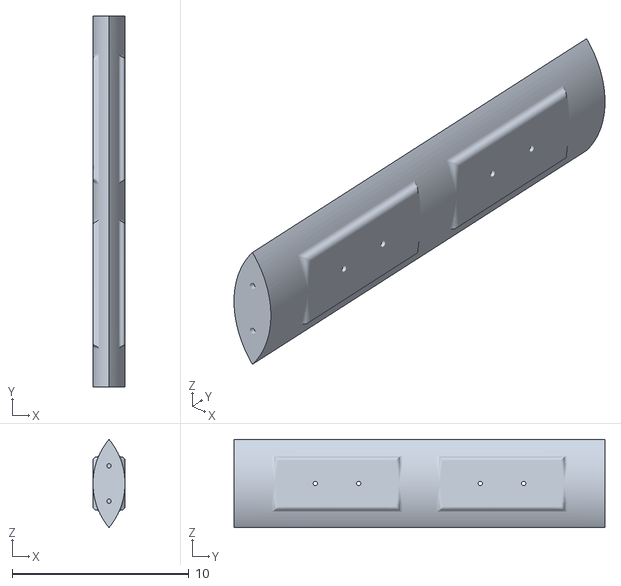
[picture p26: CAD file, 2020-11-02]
hardware/hybrid_wood/uvcholder_wood.stl
1.81 x 21.0 x 5.00

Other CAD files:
hardware/hybrid_alu/lichtschutz.stl
hardware/all_3dprinted/universalBoxPlate_clean.stl
hardware/all_3dprinted/lichtschutz.stl
hardware/common/uv_back_holder.stl
hardware/all_3dprinted/universalBoxPlate_io.stl
hardware/all_wood/light shutters/shutter_mount.dxf
hardware/all_wood/light shutters/shutter_mount.stl
hardware/common/honeycombfront_lowprofile_fan.stl

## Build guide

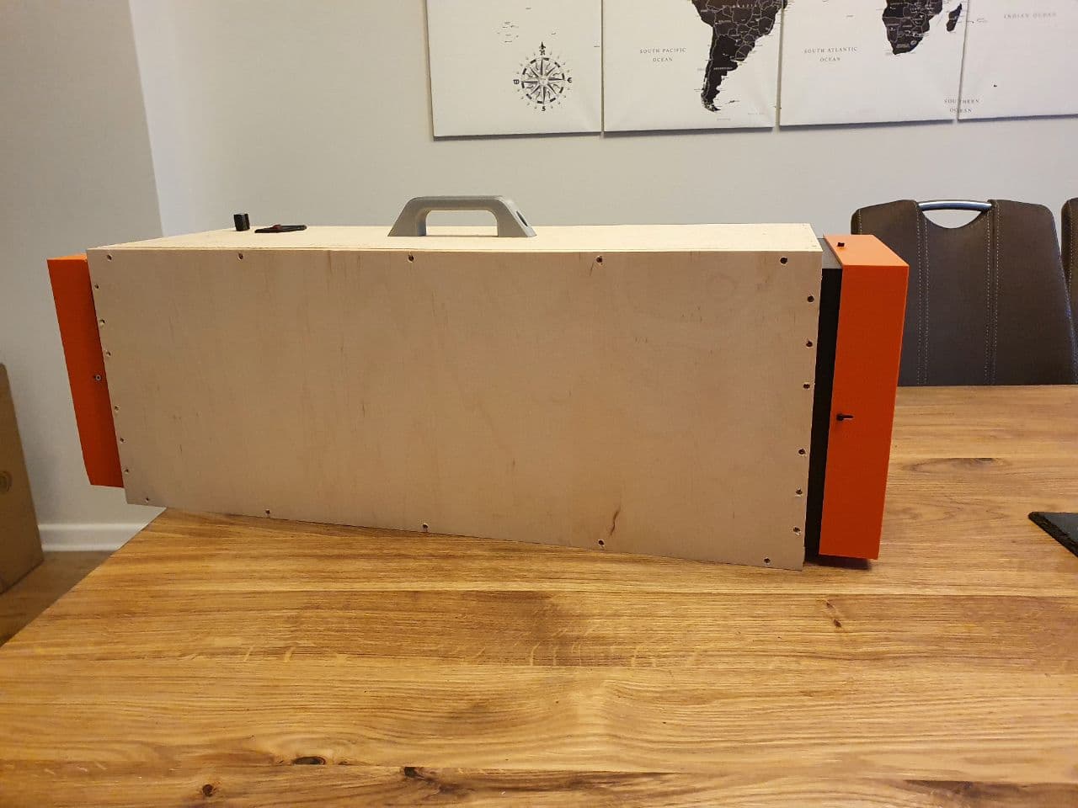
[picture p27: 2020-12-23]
documentation/images/3d_printable/side_view_2.jpg

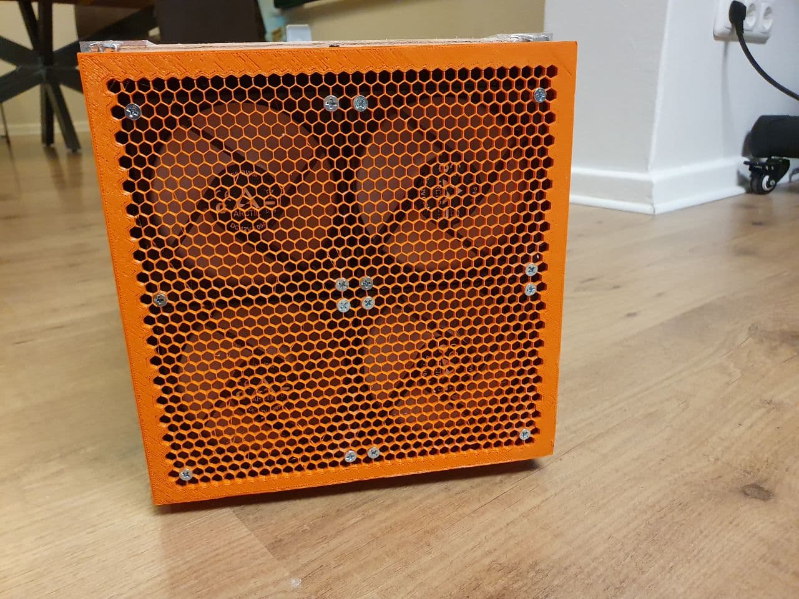
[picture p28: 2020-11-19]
documentation/images/3d_printable/fan_view.jpg

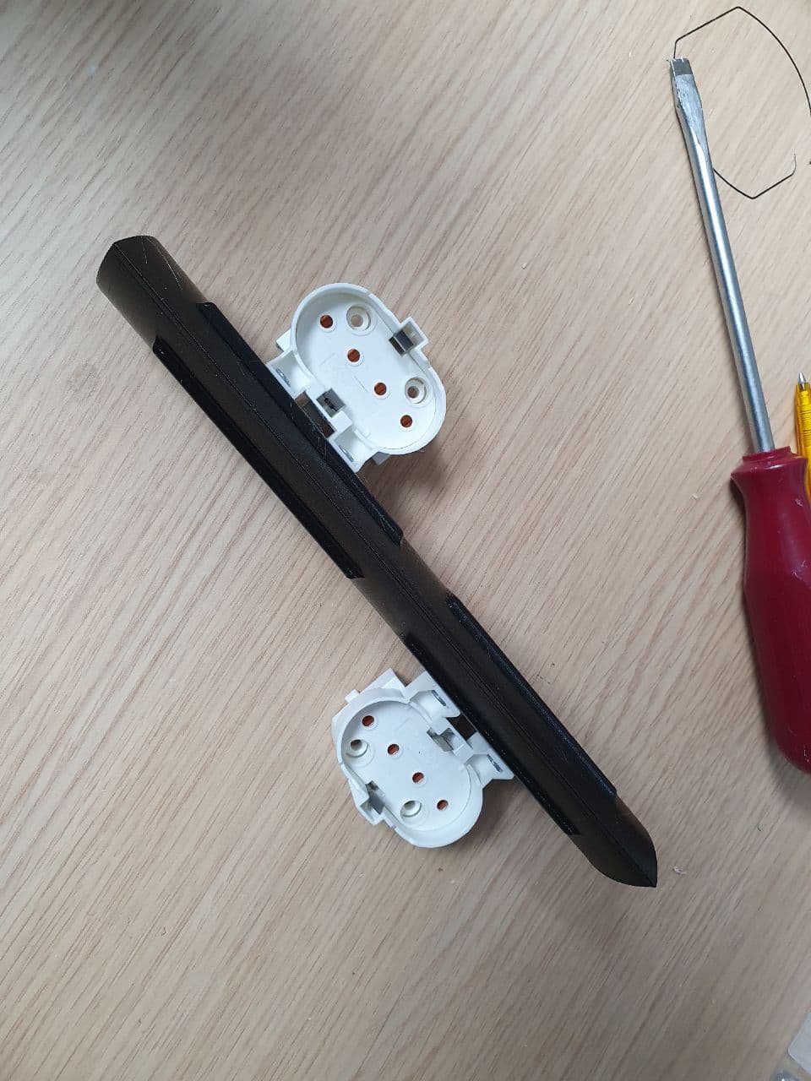
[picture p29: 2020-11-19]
documentation/images/3d_printable/uvc_holder_unwrapped.jpg

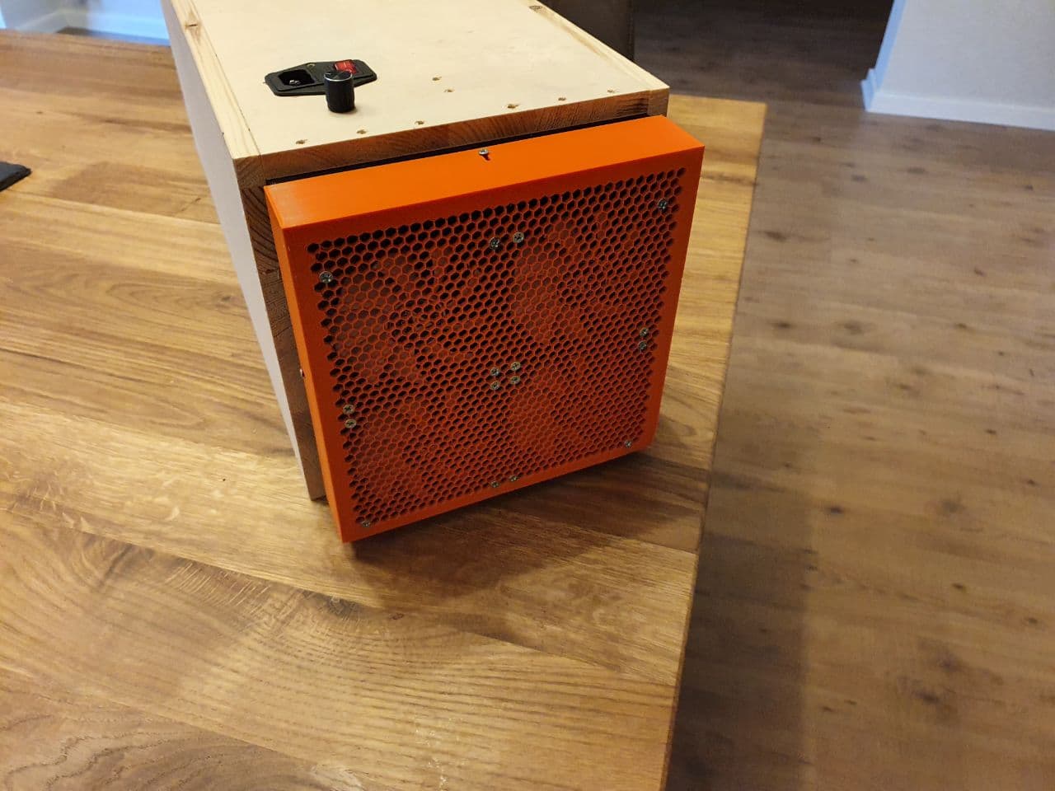
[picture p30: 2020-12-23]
documentation/images/3d_printable/front_view_2.jpg

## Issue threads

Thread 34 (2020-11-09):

Knob in max. position does not add maximum speed to the fans

thegreatdane6, 2020-11-09:
Observed the following:
- wired the fans to the arduino
- started to control the fans via the knob
-> fans should run on max speed
- jumped the pwm signal (no controle via the knob)
-> fan ran about at least two times fast than with the control of the arduino

Closed 2020-11-12.

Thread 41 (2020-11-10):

Add Neopixel Led Stick to indicate device status

angrox, 2020-11-10:
**Is your feature request related to a problem? Please describe.**
As a clean air device user I want to have a visual feedback of the status of the device.

**Describe the solution you'd like**
I like to have leds showing the various stati: Booting, Updating, Error, Normal Operation, Maintenance needed, ...
I propose to use a NeoPixel Led Stick which is highly configureable in terms of color and only needs one GPIO pin.

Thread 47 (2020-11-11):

Open clean air slack and link to documentation

angrox, 2020-11-11:
**Is your feature request related to a problem? Please describe.**
As a clean air contributer I want to work in a more collaborative way with other contributers using Slack. Open the currently closed clean air slack and post the information in the documentation section and/or the main README.

Closed 2020-11-11.

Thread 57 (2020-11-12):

Create releases on version tagging

angrox, 2020-11-12:
**Is your feature request related to a problem? Please describe.**
As a clean air developer I want a github release created when a certain tag is created.

**Describe the solution you'd like**
Whenever a tag is created which matches `^v*` (e.g. v1.0.0) a release should be created and the firmware build file should be attached to it.

angrox, 2020-11-12:
This issue is a prerequisite to fulfill #56

Closed 2020-11-14.

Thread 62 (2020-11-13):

Device does not always connect itself to the wifi

thegreatdane6, 2020-11-13:

angrox, 2020-11-15:
Can you say what you did when the error occured, @thegreatdane6

thegreatdane6, 2020-11-16:
I am still investigating. I do think that it just takes really long to establish the wifi connection, which i cannot explain. On my testbench it works seemlessly..

angrox, 2020-11-17:
I am sure it as to do with the wifi connect part of the AutoConnect library. I had the issue myself and my device is without any shielding around

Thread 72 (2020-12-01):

Only do an upgrade if the version on the repo is greater than that of the currently running software

mlkiefer, 2020-12-01:
Currently, the check for available updates runs rather blindly. If the versions differ, it pulls the bin of the latest release from the server and flashes it onto the device. This also happens with the firmware used during development.

We should add something that prevents updating the dev firmware with a release. Otherwise we won't be able to test our changes.

mlkiefer, 2020-12-01:
not an issue catually

Closed 2020-12-01.

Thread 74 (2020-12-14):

Devices max. flash size exceeded

thegreatdane6, 2020-12-14:
We need to reduce the flash size or adjust the partitions because currently we are using 105% of the flashs size

angrox, 2020-12-17:
This is probably a problem of the board configuration in platformio. Currently we are using a ESP32-WROOM-32 Unit bought from AZ-Delivery. This device seems to have 4MB eeprom and 520 kb ram. The platformio configuration has a board configured which shows 4mb eeprom and 320 kb ram.

Documentation links:
* https://www.espressif.com/sites/default/files/documentation/esp32-wroom-32_datasheet_en.pdf
* https://www.az-delivery.de/en/products/esp32-d1-mini#description

Closed 2020-12-19.

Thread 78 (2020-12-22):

Fanspeed gets reset every X seconds

thegreatdane6, 2020-12-22:
This is possibly due to the aux fan and the main fan using the same channel in the code.

Closed 2020-12-23.

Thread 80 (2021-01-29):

Build visual Feedback with LEDs

felixherbst, 2021-01-29:
8 WS2812b LEDs can be used to display the current status. Some visualization ideas:

-show the current fan speed in 8 steps, only when the user is actually turning the knob plus some seconds after the interaction
-startup animation while booting or searching for wifi, maybe a ping pong animation
-status codes, like orange blinking during wifi setup

What needs to be done:
-setup the LEDs and define start state
-implement one ore more visualizations

Technical information:
On the CleanAirPCB v1, 8 WS2812b LEDs are connected to IO18 and succesfully tested with the Adafruit NeoPixel Library.

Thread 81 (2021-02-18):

Import of STLs into Slicer -> too small

thorsten, 2021-02-18:
**Describe the bug**
I cloned the repo and imported the STLs in PrusaSclicer. They look very small, only 21x21mm for the Lichtschutz.

**Screenshots**
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

**Hardware (please add the relevant information):**
 - Prusa MK3S+

**Software (please add the relevant information):**
 - PrusaSlicer 2.3

thegreatdane6, 2021-02-18:
I will fix this, this is due to some export error. A workaround for this is to skale the part up to 1000% :)

thorsten, 2021-02-18:
210x210mm is too large?

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

felixherbst, 2021-02-18:
210*210 fits on a prusa, if you remove the skirt ("Schürze"). Just set the amount to 0.
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

Closed 2022-12-31.

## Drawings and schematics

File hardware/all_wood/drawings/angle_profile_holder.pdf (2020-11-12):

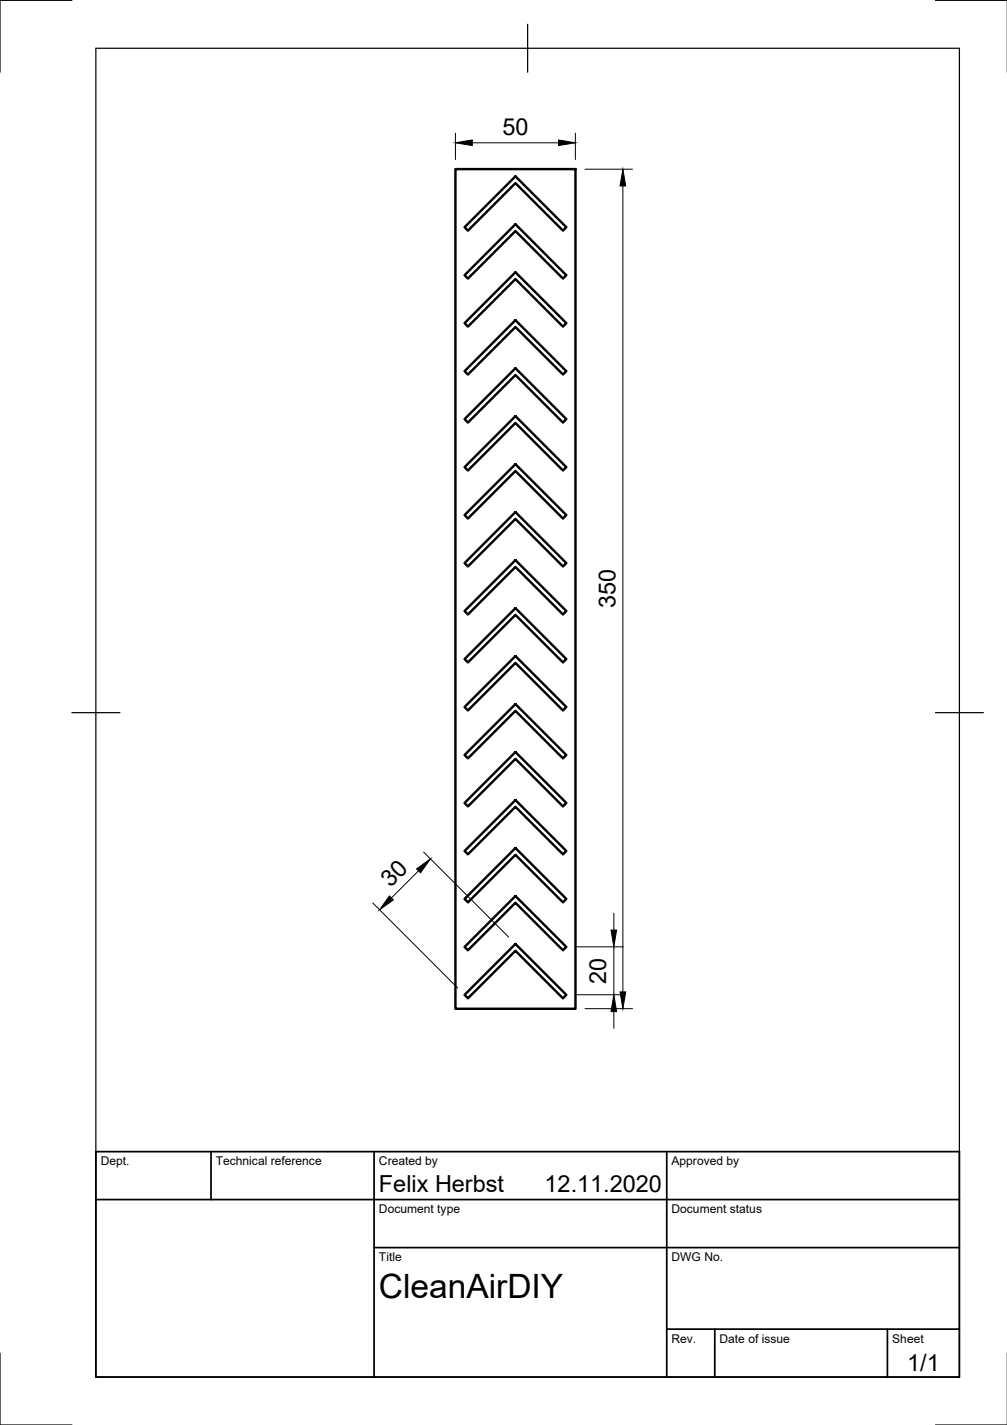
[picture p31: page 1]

Dept. | Technical reference | Created by Felix Herbst 12.11.2020 | Approved by

Document type | Document status

Title CleanAirDIY | DWG No.

Rev. | Date of issue | Sheet 1/1

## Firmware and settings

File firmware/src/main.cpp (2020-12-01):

/**
 * Clean Air Main.
 */

#define LOG_LOCAL_LEVEL ESP_LOG_VERBOSE

#include <AutoConnect.h>
#include <FS.h>
#include <LITTLEFS.h>
#include <RotaryEncoder.h>
#include <WebServer.h>
#include <WiFi.h>
#include "Arduino.h"
#include "debug.h"
#include "defaults.h"
#include "esp_log.h"
#include "fanController.h"
#include "json.h"
#include "jsonHandler.h"
#include "rotary.h"
#include "operationHourCounter.h"
#include "updateService.h"
#include "caseTempController.h"

void setFanSpeed(int speed);

// Variables
// ota URL
String otaUrl;
boolean otaUrlConfigured = false;

// Set in setup() if we fall to offline mode
boolean offlineMode = false;

// Define the jsonHandler.
JsonHandler jsonHandler;

// Define the statisticsHandler.
OperationHourCounter operationHourCounter;

// Define the fans controller.
FanController fanController;

// Define case temperature controller.
CaseTempController caseTempController;

// Define the adpter to handle hardware related io things.
Rotary rotary;

// Define custom update service.
UpdateService updateService;

// Define webserver variable and tell autoconnect to use it
WebServer Server;
AutoConnect Portal(Server);

// Config Object
AutoConnectConfig WifiConfig;

// Custom Websites
AutoConnectCredential WifiCredentials;
AutoConnectAux otaSetting;
AutoConnectAux otaSave;

// Webserver: serve a default page
void rootPage()
{
  char content[] = "Clean Air dummy site";
  Server.send(200, "text/plain", content);
} // rootPage

// Autoconnect: when AP is started print message and turn internal led on
bool startCP(IPAddress ip)
{
  digitalWrite(LED_BUILTIN, HIGH);
  ESP_LOGI(TAG, "CP started, IP: %s", WiFi.localIP().toString());
  return true;
} // startCP

// Get parameters from AutoConnectElement
void getParams()
{
  otaUrl = otaSetting.getElement<AutoConnectInput>(OTA_URL_KEY).value;
  otaUrlConfigured = true;
  otaUrl.trim();
  jsonHandler.parameter[OTA_URL_KEY] = otaUrl;
  updateService.setServerUrl(otaUrl);
}

// Load parameter from eeprom fs
void loadOtaUrl()
{
  // Load the elements with parameters
  const char *url = jsonHandler.parameter[OTA_URL_KEY];
  otaUrl = url;
  if (otaUrl != "")
  {
    otaSetting.setElementValue(OTA_URL_KEY, otaUrl);
    getParams();
    updateService.setServerUrl(otaUrl);
  }
} // loadParams

// Handler for custom webpage, needed to save data to eeprom
String onSave(AutoConnectAux &aux, PageArgument &args)
{
  getParams();
  jsonHandler.storeParameter();
  return "Saved";
}

// Configures network related stuff during setup.
void configureNetwork()
{
  ESP_LOGD(TAG, "Configure Wifi: begin");

  // Configure Wifi Settings

  String hostName = "cleanair-" + String((uint32_t)ESP.getEfuseMac(), HEX);

  WifiConfig.hostName = hostName;
  WifiConfig.autoRise = false; // Disable CP portal. This is needed for "offline mode"
  WifiConfig.autoReconnect = true;
  WifiConfig.apid = AP_SSID;

  // Check if rotary button is pressed and start CP
  if (digitalRead(KY_SW) == LOW)
  {
    WifiConfig.immediateStart = true;
    WifiConfig.autoRise = true; // autorise must be true if we want to enter CP mode
    ESP_LOGI(TAG, "Rotary button pressed. Will start config AP and CP");
  }

  ESP_LOGD(TAG, "WiFi connections: %d", WifiCredentials.entries());

  WifiConfig.autoReconnect = true;
  WifiConfig.apid = AP_SSID;
  Portal.config(WifiConfig);

  // detect captive portal
  Portal.onDetect(startCP);

  // Serve default webpage
  ESP_LOGD(TAG, "Serving webpage");
  Server.on("/", rootPage);

  // Load and set the custom configuration web page for ota updates
  otaSetting.load(otaSettingPage);
  loadOtaUrl();
  otaSetting.menu(true);
  otaSave.load(otaSavePage);
  otaSave.on(onSave);  // custom handler when this site is called
  otaSave.menu(false); // hidden, only called from otaSettingPage

  Portal.config(WifiConfig);
  // Start the server
  Portal.join({otaSetting, otaSave});

  ESP_LOGD(TAG, "%d", WifiCredentials.entries());

  if (offlineMode == false) // if we already in offline mode skip portal startup
  {
    if (Portal.begin())
    {
      ESP_LOGI(TAG, "Webserver started: %s", WiFi.localIP().toString().c_str());
    }

    delay(1000);

    if (WiFi.status() != WL_CONNECTED && WifiConfig.autoRise == false)
    {
      ESP_LOGW(TAG, "Wifi not connected - offline mode");
      offlineMode = true;
    }
  }

  ESP_LOGD(TAG, "Configure Wifi: complete");
}

// TODO: no idea how to stuff the setspeed func directly into the confiure
void setFanSpeed(int speed)
{
  fanController.setSpeed(speed);
}

// Setup: Called once at bootup
void setup()
{
  esp_log_level_set("*", ESP_LOG_ERROR);
  esp_log_level_set(TAG, ESP_LOG_VERBOSE);

  Serial.begin(BAUD_RATE);

  ESP_LOGI(TAG, "Setup initiated");

  // Define the jsonHandler.
  jsonHandler.setup();
  operationHourCounter.setup(jsonHandler);
  fanController.setup();
  rotary.setup(jsonHandler, setFanSpeed);
  updateService.setup(jsonHandler);

  caseTempController.init();

  configureNetwork();

  ESP_LOGI(TAG, "Setup complete %s", TAG);
  ESP_LOGD(TAG, "offlineMode: %d", offlineMode);
  ESP_LOGD(TAG, "otaUrlConfigured: %d", otaUrlConfigured);
  ESP_LOGD(TAG, "fanspeed: %d", jsonHandler.statistics[FAN_SPEED_KEY].as<int>());
  ESP_LOGD(TAG, "operating hours: %lu", jsonHandler.statistics[OPERATING_HOURS_KEY].as<u_long>());
  ESP_LOGD(TAG, "version: %s", jsonHandler.parameter[VERSION_KEY].as<String>());
} // setup

// Loop: Main
void loop()
{
  if (WiFi.status() == WL_CONNECTED)
  {
    // Check if new a new update is available.
    updateService.checkAndUpdateSoftware();
  }

  operationHourCounter.countOperationHours();

  // Handle clients
  Portal.handleClient();

  // handlet the current rotary position
  rotary.handle();

  // regulate case temperature
  caseTempController.readTemperatureAndAdjustFanSpeed();
} // loop

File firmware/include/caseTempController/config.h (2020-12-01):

//*****************************************//
// configuration                           //
//*****************************************//
#define K_P                1        // proportional factor of the PID controller
#define K_I                0.1      // integral factor of the PID controller
#define K_D                0.5      // derivative factor of the PID controller
#define TAU                20       // number of measurements viewed in calculation, reduce to save space and calculation times
#define GOAL_TEMP          30       // goal temperature of 30°C
#define TEMP_GPIO          26       // the GPIO data pin of the temperature sensor
#define FAN_GPIO           23       // the PWM pin for fan control
#define FAN_PWM_CHANNEL    0        // the PWM channel for fan control
#define SLEEP              30000    // defines how many loop-throughs the controller will wait until measuring again

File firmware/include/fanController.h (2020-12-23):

// Pin Mapping
#define FAN_PWM 33

// PWM configuration
#define FAN_FREQ 25000
#define FAN_RES 8
#define FAN_MAIN_CHANNEL 1

const int FAN_SPEED_1 = -1;
const int FAN_SPEED_2 = -1;
const int FAN_SPEED_3 = -1;
const int FAN_SPEED_4 = -1;

class FanController
{
public:
    // configures the knob to be able to interact with.
    void setup(/*void (*speedHandler)(int, int, int, int)*/);

    // Sets the fans speed according to the number handed in.
    void setSpeed(int);

    // Not implemented yet, but can later on be used to emit the fans speed.
    void emitFanSpeed();
};

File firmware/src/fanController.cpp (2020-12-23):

#include "Arduino.h"
#include "fanController.h"
#include "rotary.h"

// The fans target speed.
int fanSpeedToRunAt;

// The speed of fan 1.
int fan_1_speed = -1;

// The speed of fan 2.
int fan_2_speed = -1;

// The speed of fan 3.
int fan_3_speed = -1;

// The speed of fan 4.
int fan_4_speed = -1;

// Handler to emit the fans speed.
void (*localSpeedHandler)(int, int, int, int);

// Configure fan related stuff during setup.
void FanController::setup(/*void (*speedHandler)(int, int, int, int)*/)
{
    //localSpeedHandler = speedHandler;
    ledcAttachPin(FAN_PWM, FAN_MAIN_CHANNEL);
    ledcSetup(FAN_MAIN_CHANNEL, FAN_FREQ, FAN_RES);
}

// TODO: this needs to run on a different thread to be able to constantly monitor the fans speed
void FanController::emitFanSpeed()
{
    localSpeedHandler(fan_1_speed, fan_2_speed, fan_3_speed, fan_4_speed);
}

// Set fan speed in percent - 0 is off, 1-100 is minimum to maximum speed
void FanController::setSpeed(int speed)
{
    ledcWrite(FAN_MAIN_CHANNEL, speed);
    fanSpeedToRunAt = speed;
}

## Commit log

2020-11-02 feat: add first batch of 3D printable parts (#22)
    * feat: add first batch of 3D printable parts
    * fix: remove step files
    * Update README.md
    * Update README.md
    * Update README.md
    * Update README.md
    * Update README.md
    * Update hardware/hybrid_alu/required_parts.txt
    * Update hardware/hybrid_wood/required_parts.txt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
    [honeycombfront_lowprofile_fan.stl, lichtschutz.stl, lichtschutz_wood.stl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]
2020-11-05 feat: add second batch of cad files (#30)
    [honeycombfront_normal_fan.stl, uv_back_holder.stl]
2020-11-10 Add warning for high voltage in README.md
2020-11-12 add shutter_mounts in multiple formats
    [shutter_mount.dxf, shutter_mount.step, shutter_mount.stl]
2020-11-12 add encoder to Readme
2020-11-12 add dc schematics
2020-11-12 pin littlefs
2020-11-12 documentation about physical background
    [irradiation.xlsx]
2020-11-12 fix: allow max possible fan speed (#55)
    [fanController.cpp]
2020-11-12 add affiliation, some more remarks
    [irradiation.xlsx]
2020-11-15 Fix retrieving of software version and store last speed indication (#61)
    * feat: fix dependency stuff
    * fix: call proper function
    * fix: error on boot
    * fix: types
    * fix: everything working properly now
    * fix: stringification
    [fanController.cpp, fanController.h, main.cpp]
2020-11-19 fix: schablone's wrong sizes
    [schablone_alu.stl]
2020-11-27 fix: kernel panic and monitoring (#69)
    [main.cpp]
2020-12-01 add case temperature controller
    case temperature controller: add library for DS18B20 temperature sensor as submodule
    case temperature controller: add OneWire library for DS18B20 temperature sensor as submodule, turn temperature source code into own class
    case temperature controller: add some more information to README
    case temperature controller: turn fan code into own class
    case temperature controller: remove loop from code
    case temperature controller: turn printf into actual log
    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
2020-12-11 fix: uv backholder add: prusa compatible honeycomb
    [honeycombfront_prusa_normal_fan.stl, uv_back_holder.stl]
2020-12-19 feat: add objects
    [230v_protector.stl, honeycombfront_normal_fan.stl, honeycombfront_prusa_normal_fan.stl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]
2020-12-21 fix: add support for redirecting (#77)
    * fix: add support for redirecting
    * fix: remove unused ref
    [updateService.cpp]
2020-12-21 feat: add case for wemos
    [wemos_case.stl]
2020-12-23 fix: changes pwm channels (#79)
    * fix: changes channels
    * feat: add schematics in doku
    * feat: add more documentation
    * feat: add more doku and pics
    * feat: add links to hardware model
    * fix: spelling mistake
    * more spelling mistakes
    [fanController.cpp, fanController.h]
